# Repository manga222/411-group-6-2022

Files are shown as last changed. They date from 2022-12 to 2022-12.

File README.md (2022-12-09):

# ECE 425 Disco Light Tower

Author: Manuel Garcia, Mercedes Newton, Willenton Bridges, Alice Ma

## Introduction

A light display tower that utilized audio input to create a unique and exciting light show. The tower will change light color and intensity according to the music in order to always create the perfect vibe. This is the perfect product for all ages, specifically anyone who enjoys music and excellent vibes. This is a practical and fun product that we could all see having in our homes.

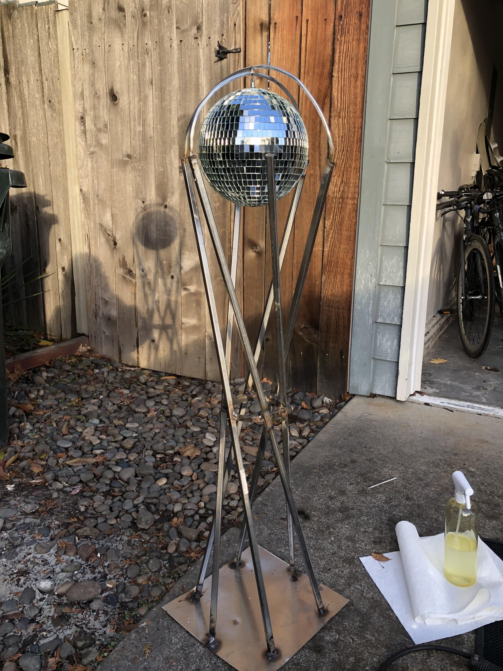
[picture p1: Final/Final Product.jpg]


### Motivation

Searching for a light centerpiece, we identified needs that we had not seen satiated in the current market
Our prototype provides a solution that is…..
* Affordable 
* Portable
* Compatible with any audio
* Unique 
* aesthetically pleasing

## Proposed Design Requirements

* Must change LED color according to surrounding sound and/or music
* Must be aesthetically pleasing
* Must be safe
* Must be user friendly (single power button)
* Must be portable
* Should change LED intensity / frequency according to surrounding sound and/or music
* Should be less than 30lbs
* Should be 2 feet tall
* Should have a metal base
* Should have a disco ball and RGB spotlight
* Should have soft bottom to prevent scratching floor
* May input music internally through microcontroller and use FFT to filter frequency
* May be battery powered
* May have light intensity settings
* May have amplifying speakers

### Physical Design

* Helix shape for optimal height, light, and appearance
* Lights attached on interior of steel bars to prevent harshness
* 6 bars to both allow for a multitude of light strips yet stay lightweight and mobile
* Circuitry placed in base and out of sight
* Disco ball centered and hung at the top of tower

### System Architecture

* ESP-32

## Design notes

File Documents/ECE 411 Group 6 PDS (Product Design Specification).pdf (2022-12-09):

Mercedes Newton
Manuel Garcia
Willenton Bridges
Alice Ma

## ECE 411 Group 6 Product Design Specification (PDS)

Executive Summary/Concept of Operations
Brief project description: A light display tower that utilized audio input to create a unique and exciting light show. The tower will change light color and intensity according to the music in order to always create the perfect vibe. This is the perfect product for all ages, specifically anyone who enjoys music and excellent vibes. This is a practical and fun product that we could all see having in our homes. There is potential for a multitude of different shapes and concepts so this project is full of possibilities.

Photo of Potential appearance:

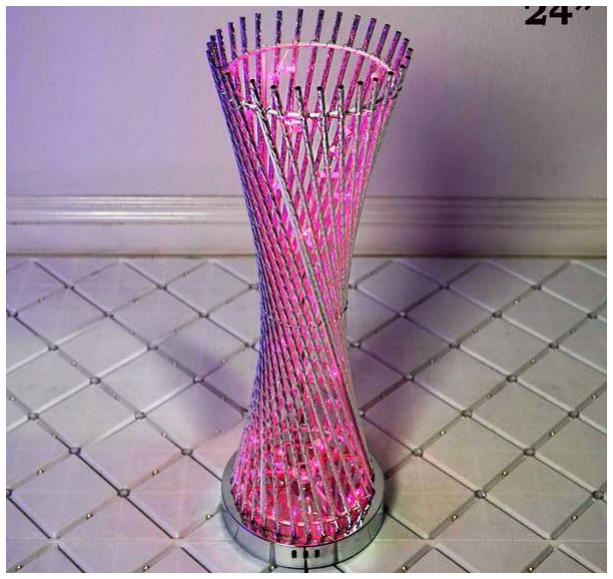
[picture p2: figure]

Brief Market Analysis
The LED light tower is intended to be enjoyed by customers of all ages! Although there are light towers of various shapes and sizes, our product will be slightly different from the competition. Our product will utilize an audio input in order to create a unique and exciting light show. The tower will change both the light color and intensity according to the music. This will always create the perfect vibe regardless of the occasion! We believe our LED light tower will sell for $30, which is slightly higher than the price range compared to the other LED light towers. Our price is slightly higher due to having the feature of the light color and intensity changing based on the pitch of the music.

Requirements

Must change LED color according to surrounding sound and/or music Must be aesthetically pleasing
Must be safe
Must be user friendly (single power button)
Must be portable
Should change LED intensity / frequency according to surrounding sound and/or music
Should be less than 30lbs
Should be 2 feet tall
Should have a metal base
Should have a disco ball and RGB spotlight
Should have soft bottom to prevent scratching floor
May input music internally through microcontroller and use FFT to filter frequency May be battery powered
May have light intensity settings
May have amplifying speakers

System Architecture

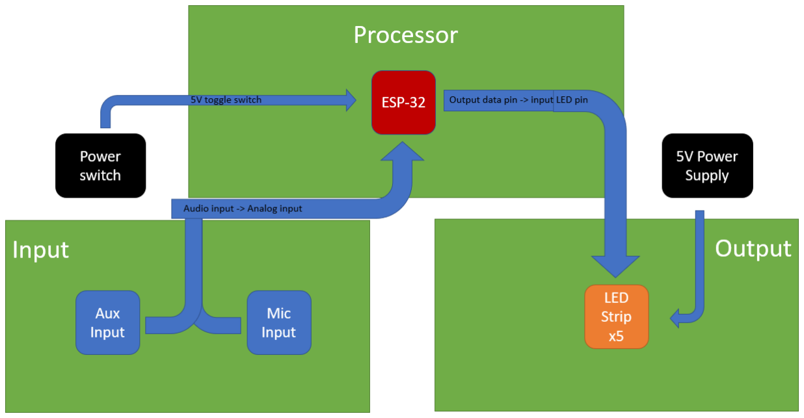
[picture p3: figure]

Design Specification
- Sensor: Microphone, auxiliary input
- Processor: LED controller
- Actuator: LEDs
- Power: 5V power source
- Mechanical design: Helix metal tower with solid base
- Firmware: ESP-32 AT firmware
- Arduino type: ESP-32
- Development environment: Arduino IDE

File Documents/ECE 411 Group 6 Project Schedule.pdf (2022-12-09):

ECE411_gantt | Nov 3, 2022 http://

# Project manager

Project dates | Oct 10, 2022 - Dec 1, 2022
Completion | 70%
Tasks | 25
Resources | 0

Duration | Name | Begin date | End date
8 | Choosing Project | 10/10/22 | 10/19/22
4 | Brainstorm Ideas | 10/10/22 | 10/13/22
2 | Decide on Project | 10/12/22 | 10/13/22
4 | Create Product Design Specifications | 10/14/22 | 10/19/22
11 | Interface Circuitry | 10/19/22 | 11/2/22
8 | Design Preliminary Schematic | 10/19/22 | 10/28/22
9 | Purchase Components | 10/19/22 | 10/31/22
6 | Construct & Test Circuits | 10/26/22 | 11/2/22
2 | Current Driver Circuitry | 10/26/22 | 10/27/22
3 | Level Offset & Gain Circuitry | 10/26/22 | 10/28/22
3 | Integrate Microphone and LED | 10/31/22 | 11/2/22
7 | Microphones and LED | 10/24/22 | 11/1/22
1 | Research A/D Converters | 10/24/22 | 10/24/22
4 | Complete Hardware Design | 10/25/22 | 10/28/22
3 | Purchase LED and Microphone | 10/25/22 | 10/27/22
2 | Construct & Test | 10/31/22 | 11/1/22
12 | System Integtration & Test | 10/26/22 | 11/10/22
4 | Test Breadboard Prototype | 10/31/22 | 11/3/22
7 | Update Schematic and Preliminary Layout | 10/26/22 | 11/3/22
4 | Create a Rough Draft in CAD | 11/3/22 | 11/8/22
3 | Conduct a Design Review | 11/8/22 | 11/10/22
14 | Final Stretch | 11/11/22 | 11/30/22
4 | Update Final Schematic Layout | 11/11/22 | 11/16/22
5 | Send PCD Design to be Printed | 11/17/22 | 11/23/22
6 | Prepare to Demp | 11/23/22 | 11/30/22
ECE411_gantt | Nov 3, 2022
Tasks | 2

# Gantt Chart

3

Duration | Name | Begin date | End date
8.0 day | Choosing Project | 10/10/22 | 10/19/22
4.0 day | Brainstorm Ideas | 10/10/22 | 10/13/22
2.0 day | Decide on Project | 10/12/22 | 10/13/22
4.0 day | Create Product Design... | 10/14/22 | 10/19/22
11.0 day | Interface Circuitry | 10/19/22 | 11/2/22
8.0 day | Design Preliminary Schematic | 10/19/22 | 10/28/22
9.0 day | Purchase Components | 10/19/22 | 10/31/22
6.0 day | Construct & Test Circuits | 10/26/22 | 11/2/22
2.0 day | Current Driver Circuitry | 10/26/22 | 10/27/22
3.0 day | Level Offset & Gain Circuitry | 10/26/22 | 10/28/22
3.0 day | Integrate Microphone and LED | 10/31/22 | 11/2/22
7.0 day | Microphones and LED | 10/24/22 | 11/1/22
1.0 day | Research A/D Converters | 10/24/22 | 10/24/22
4.0 day | Complete Hardware Design | 10/25/22 | 10/28/22
3.0 day | Purchase LED and Microphone | 10/25/22 | 10/27/22
2.0 day | Construct & Test | 10/31/22 | 11/1/22
12.0 day | System Integtration & Test | 10/26/22 | 11/10/22
4.0 day | Test Breadboard Prototype | 10/31/22 | 11/3/22
7.0 day | Update Schematic and ... | 10/26/22 | 11/3/22
4.0 day | Create a Rough Draft in CAD | 11/3/22 | 11/8/22
3.0 day | Conduct a Design Review | 11/8/22 | 11/10/22
14.0 day | Final Stretch | 11/11/22 | 11/30/22
4.0 day | Update Final Schematic Layout | 11/11/22 | 11/16/22
5.0 day | Send PCD Design to be Printed | 11/17/22 | 11/23/22
6.0 day | Prepare to Demp | 11/23/22 | 11/30/22
October 2022 | November 2022 | Dec'2022
10 | 11 | 12 | 13 | 14 | 17 | 18 | 19 | 20 | 21 | 24 | 25 | 26 | 27 | 28 | 31

1

2

3
4

7

8

9 | 10 | 11 | 14 | 15 | 16 | 17 | 18 | 21 | 22 | 23 | 24 | 25 | 28 | 29 | 30

1

# Resources Chart

4

Name | Default role
October 2022 | November 2022 | Dec'2022
10 | 11 | 12 | 13 | 14 | 17 | 18 | 19 | 20 | 21 | 24 | 25 | 26 | 27 | 28 | 31

1

2

3
4

7

8

9 | 10 | 11 | 14 | 15 | 16 | 17 | 18 | 21 | 22 | 23 | 24 | 25 | 28 | 29 | 30

1

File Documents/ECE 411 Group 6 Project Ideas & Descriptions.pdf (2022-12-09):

Mercedes Newton
Manuel Garcia
Willenton Bridges
Alice Ma

## ECE 411 Group 6 Project Ideas & Descriptions

LED Light Tower

Brief project description: A light display tower that utilized audio input to create a unique and exciting light show. The tower will change light color and intensity according to the music in order to always create the perfect vibe.

Photo:

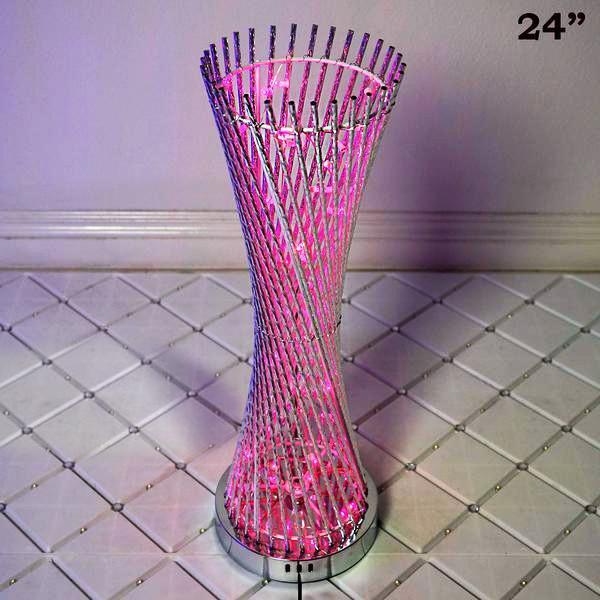
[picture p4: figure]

Sensors: Mic / Aux input

Controllers: ESP-32, LED controller

Actuators: LED’s

We like this project because: This is a practical and fun product that we could all see having in our homes. We liked the customizability and the fact that we could produce several different shapes and designs. This seems like the perfect balance of ambitious and feasible and therefore we will be pursuing this project.

Willenton Bridges
Alice Ma

Bath Time Water Temperature Sensor

Brief project description: A light up bath toy that indicates the temperature of the water with leds. Similar concept to the photo below, but with more utility as it will react to its environment and let the user know temperature.

Photo:

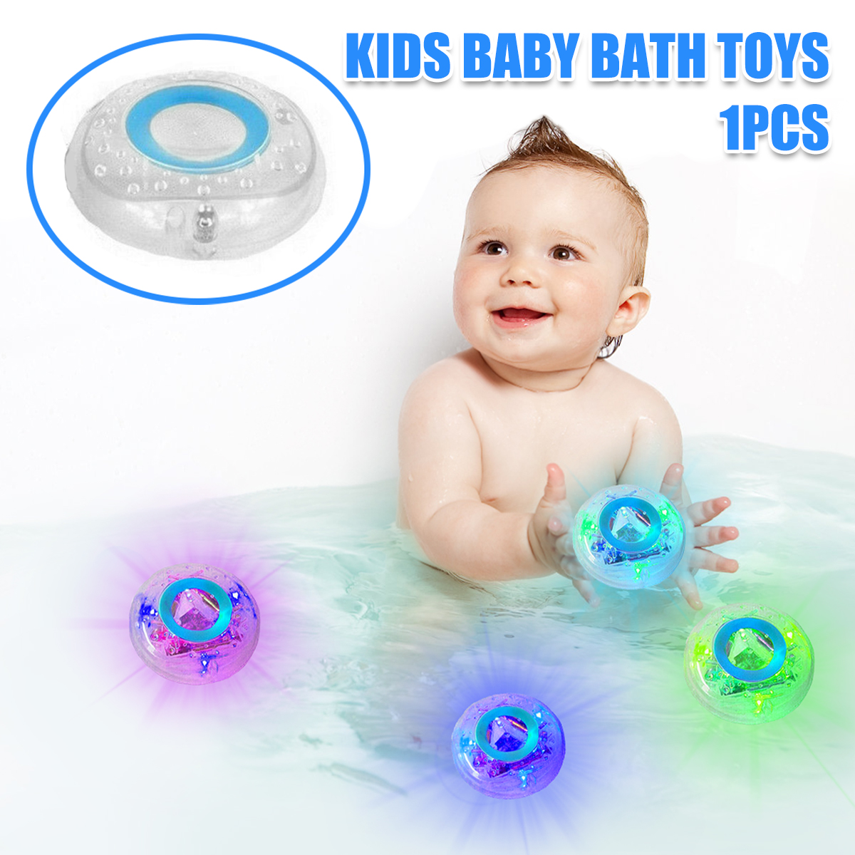
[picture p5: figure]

Sensors: Temperature sensor

Controllers: ESP-32

Actuators: RGB leds

We like this project because: This project is a fun and exciting way to incorporate light and temperature to create a helpful product. This toy could be used to help parents indicate the temperature of the water for small children, or to help let bath enthusiasts know when it is time to grab a glass of wine and settle in.

Smart Aeroponics Setup

Brief project description: This product is a self watering plant tower. The plants will be placed at different heights along the tower and the desired amount of water will be

Willenton Bridges
Alice Ma
dispersed from the main tank as depicted below.

Photo:

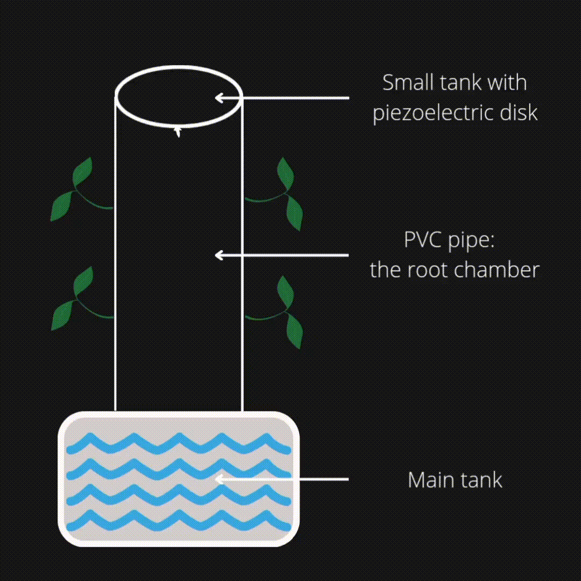
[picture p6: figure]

Sensors: PH sensor, Moisture sensor, Light sensor

Controllers: ESP-32

Actuators: Water pump, Full spectrum LED bulbs, nutrient pump

We like this project because: This is an exciting project that combines the passion of growing plants that each of our group members have, with an integrated electronics project. This would also be a fun project to use after this class is over, and would be something that we would like to keep around.

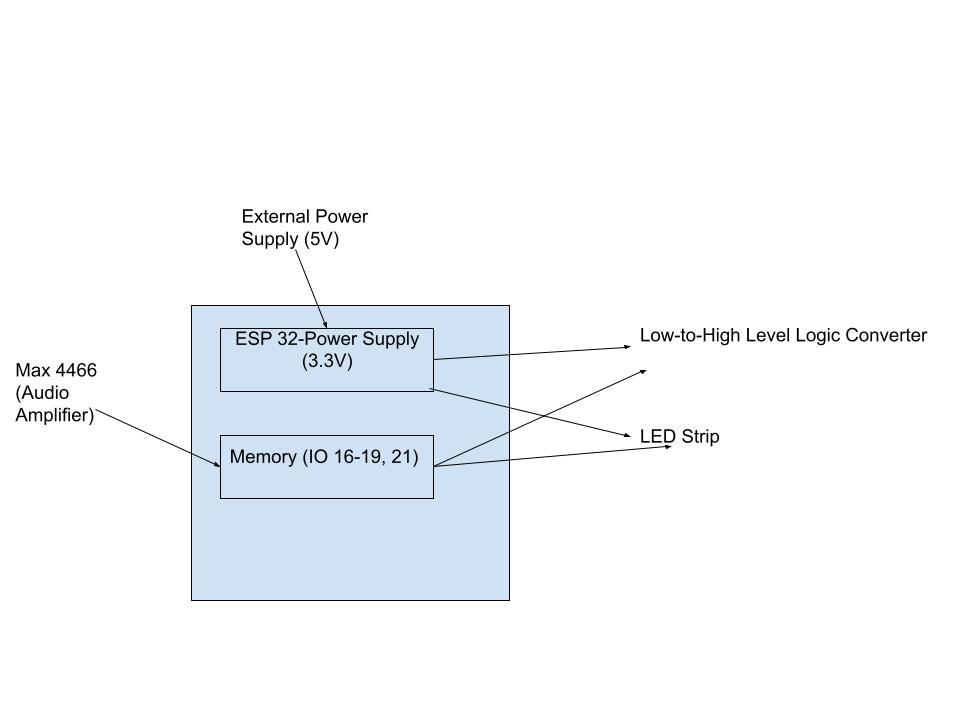
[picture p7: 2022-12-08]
Functional Decomposition/Level 1 ESP-32.jpg

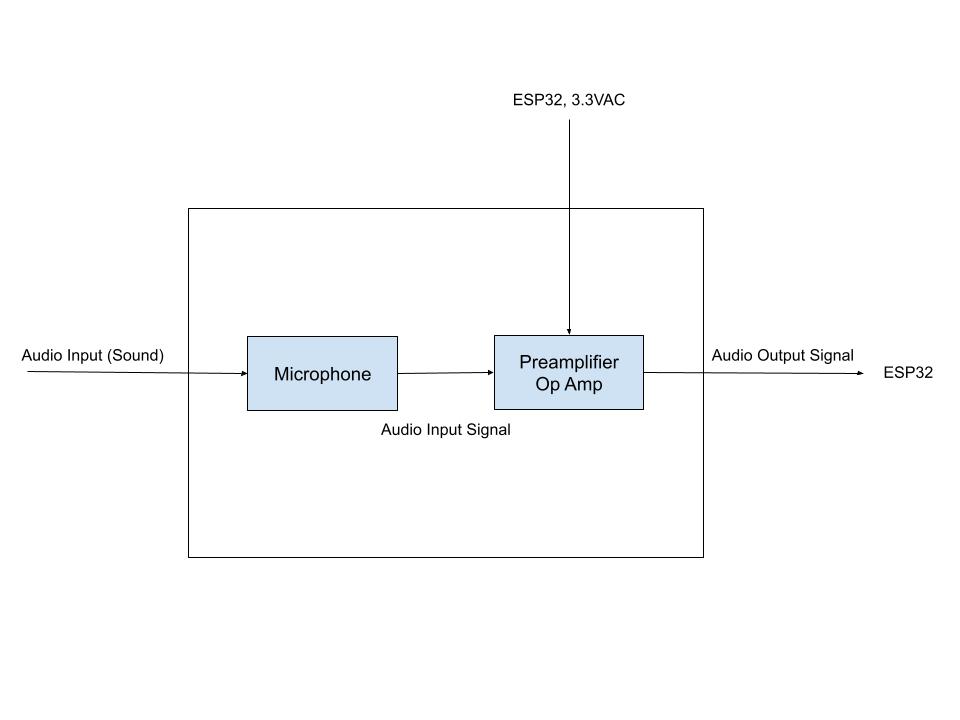
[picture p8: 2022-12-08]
Functional Decomposition/Level 1 Audio Amp.jpg

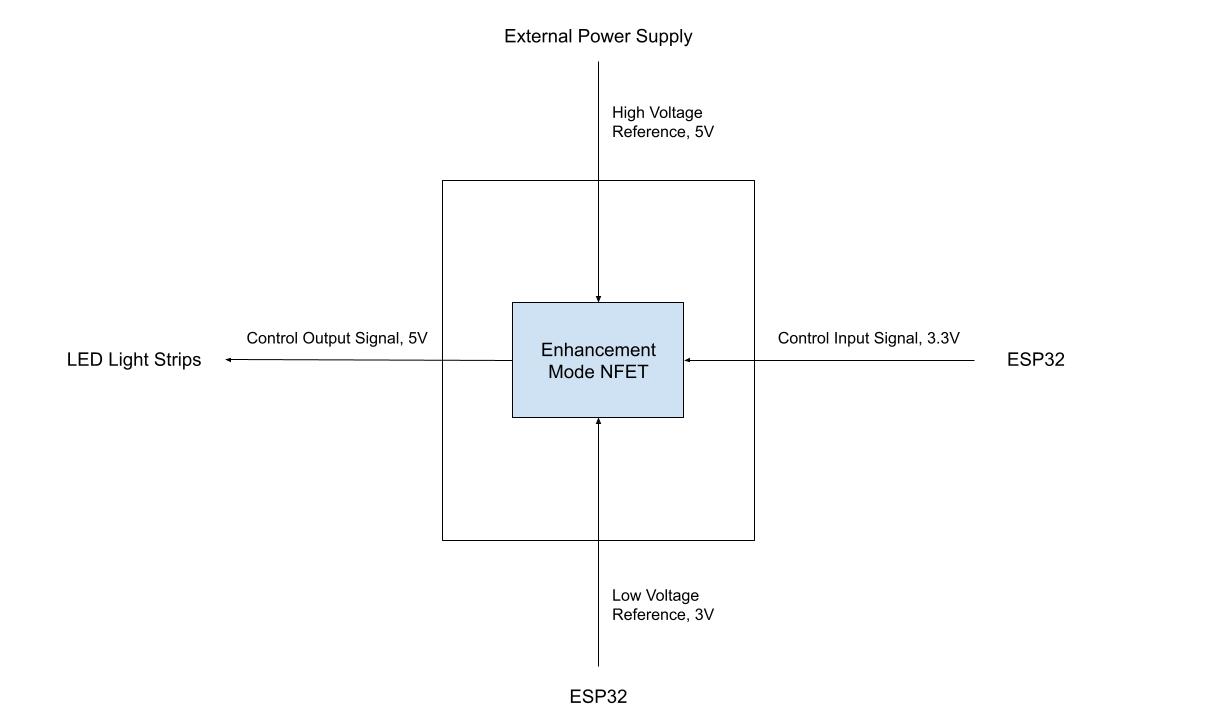
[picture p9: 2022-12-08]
Functional Decomposition/Level 1 Low to High Level Logic Converter.jpg

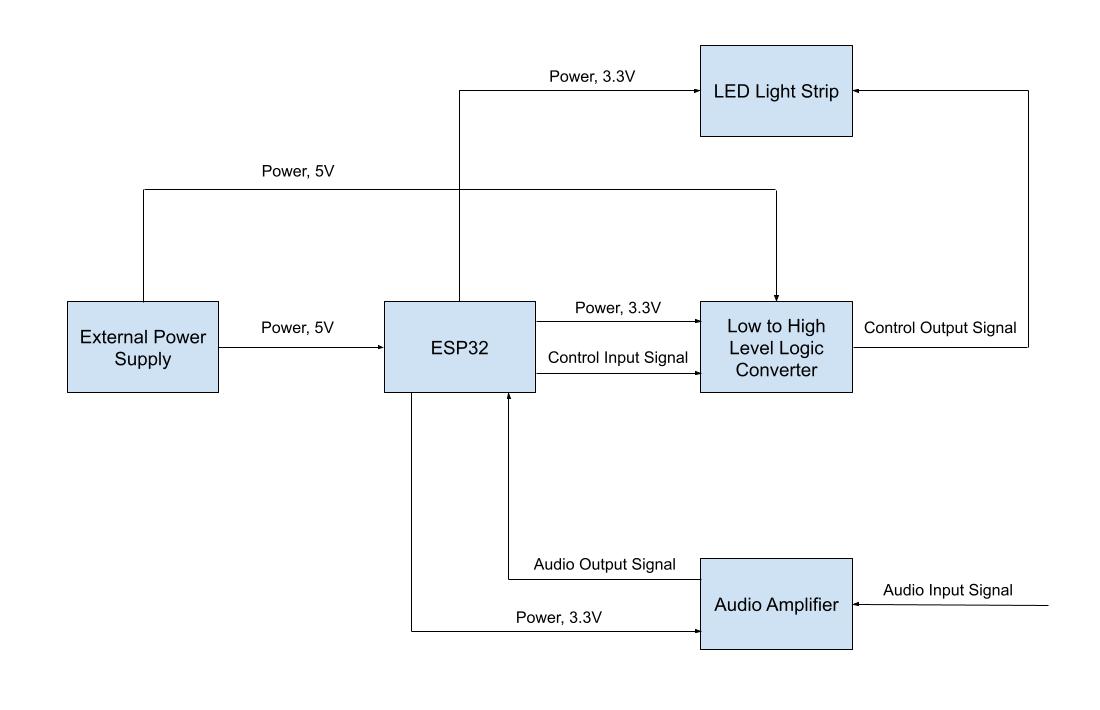
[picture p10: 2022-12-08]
Functional Decomposition/Level 0 Functional Decomposition.jpg

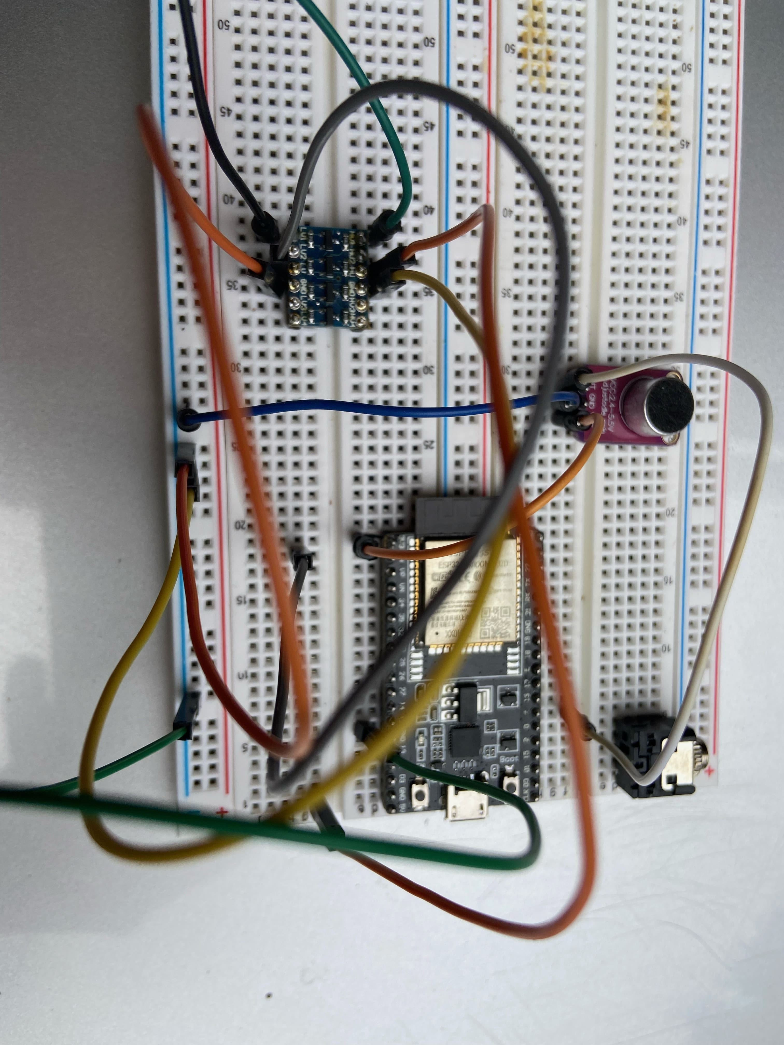
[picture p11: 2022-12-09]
Prototype/Breadboard Prototype.jpeg

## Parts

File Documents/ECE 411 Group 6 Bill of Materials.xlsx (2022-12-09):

Bill Of Materials for: Team 6, Light Tower
Last modified: 11/10/2022
PCB version: 4
BOM revision: 2 |  | P/NP | = Place/Not Place (components marked NP are not stuffed on the board)
ID | Qty | Ref Des | Value | Package | ICs | Description
1 | 3 | C1, C3, C21 | 22 uF/10V (20%) | 603 | Capacitor | Ceramic Capacitor
2 | 4 | C9, C14, C19, C22 | 0.1 uF/50V (10%) | 402 | Capacitor | Ceramic Capacitor
3 | 1 | C20 | 4.7 uF/6.3V (10%) | 402 | Capacitor | Ceramic Capacitor
4 | 1 | D1 | RED LED | 603 | Diode | light-emitting diode: Red
5 | 1 | D2 | ESP-WROOM-32 | ESP32_MODULE | Module | ESP32-WROOM-32 (32 Mbit)
6 | 1 | D3 | BAT760-7 | SOD323 | Diode | Schottky Diode,Vrrm=30V, Vr=21V, I=1A, IFSM=5.5A
7 | 3 | D4, D5, D6 | LESD5D5.0CT1G | SOD-523 | Diode | ESD, TVS Diode, 5V
8 | 1 | J1 | Micro USB Type B Female 5 Pin DIP/插件 | USB_5P | Connector | Micro USB
9 | 2 | Q1, Q2 | S8050 | SOT-23-3 | Transistor | Transistor
10 | 2 | R2, R24 | 2K (5%) | 402 | Resistor | Chip Resistors
11 | 3 | R11, R21, R22 | 10K (5%) | 402 | Resistor | Chip Resistors
12 | 2 | R17, R18 | 0R (5%) | 402 | Resistor | Chip Resistors
13 | 1 | R25 | 22.1K (5%) | 402 | Resistor | Chip Resistors
14 | 1 | R26 | 47.5K (5%) | 402 | Resistor | Chip Resistors
15 | 2 | SW1, SW2 | SW push button | Tact Switch | Tact Switch | (reset button, 2-pin, 3x4x2, SMT)
16 | 2 | J2, J3 | CON19X1_2P54 | CON19_2P54 | Connector | Male PCB Single Row Straight Header Connector, 2.54 mm Pitch, 19 Pins
17 | 1 | U1 | CP2102N-A01-GQFN28 | CP2102_QFN_28P | Interface ICs | USB-to-UART,USB2.0 full speed, data rate up to 3M baud
18 | 1 | U2 | AMS1117-3.3 | SOT-223 | Power ICs | LDO, 5V 转 3.3V 固定输出, 1A, SOT-223 (LDO, 5V/3.3V, 1A, SOT-223)
NEED TO SORT
Item | Qty | Reference(s) | Value | LibPart
1 | 3 | C1, C2, C8 | 22uF | Device:C
2 | 1 | C3 | 4.7uF | Device:C
3 | 6 | C4, C5, C6, C7, C9, C10 | 0.1uF | Device:C
4 | 1 | C11 | 10uF | Device:C
5 | 1 | C12 | 0.01uF | Device:C
6 | 1 | C13 | 100pF | Device:C
7 | 1 | D1 | RED LED | Device:LED
8 | 3 | D2, D4, D5 | D_TVS | Device:D_TVS
9 | 1 | D3 | D_Zener | Device:D_Zener
10 | 5 | D6, D7, D8, D9, D10 | WS2812 | LED:WS2812
11 | 2 | FB1, FB2 | FerriteBead | Device:FerriteBead
12 | 1 | J1 | USB_B_Micro | Connector:USB_B_Micro
13 | 1 | J2 | Conn_01x04_Male | Connector:Conn_01x04_Male
14 | 3 | J3, J4, J5 | Conn_01x08_Male | Connector:Conn_01x08_Male
15 | 1 | J6 | Conn_01x03_Male | Connector:Conn_01x03_Male
16 | 1 | MK1 | Microphone_Condenser | Device:Microphone_Condenser
17 | 2 | Q1, Q2 | QNPN | pspice:QNPN
18 | 5 | Q3, Q4, Q5, Q6, Q7 | BSS138 | Transistor_FET:BSS138
19 | 1 | R1 | 2K | Device:R
20 | 1 | R2 | 22.1k | Device:R
21 | 1 | R3 | 47.5k | Device:R
22 | 1 | R4 | 2k | Device:R
23 | 4 | R5, R7, R9, R10 | 10k | Device:R
24 | 2 | R6, R8 | 0 | Device:R
25 | 2 | R11, R12 | 1K | Device:R
26 | 1 | R13 | 22K | Device:R
27 | 2 | R14, R15 | 1M | Device:R
28 | 1 | R16 | 100K | Device:R
29 | 10 | R17, R18, R19, R20, R21, R22, R23, R24, R25, R26 | 10K | Device:R
30 | 1 | RV1 | 100K_Potentiometer | Device:R_Potentiometer
31 | 2 | SW1, SW2 | SW_MEC_5G | Switch:SW_MEC_5G
32 | 1 | U1 | AMS1117-3.3 | Regulator_Linear:AMS1117-3.3
33 | 1 | U2 | CP2102N-Axx-xQFN28 | Interface_USB:CP2102N-Axx-xQFN28
34 | 1 | U3 | ESP32-WROOM-32 | RF_Module:ESP32-WROOM-32
35 | 1 | U4 | MAX4466 | Custom_Parts:MAX4466
VERSION INFO
Rev | Date | Notes

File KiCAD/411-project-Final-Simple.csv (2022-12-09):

Source: | C:\Users\manue\Documents\KiCad\411-project-Final-Simple\411-project-Final-Simple.kicad_sch
Date: | 11/13/2022 10:49:24 PM
Tool: | Eeschema (6.0.8)
Generator: | C:\Program Files\KiCad\6.0\bin\scripting\plugins/bom_csv_grouped_by_value.py
Component Count: | 50
Individual Components:
Item | Qty | Reference(s) | Value | LibPart | Footprint | Datasheet | MANUFACTURER | PARTREV
 |  | C1 | 0.1uF | Device:C |  | ~
 |  | C2 | 10uF | Device:C |  | ~
 |  | C3 | 0.01uF | Device:C |  | ~
 |  | C4 | 100pF | Device:C |  | ~
 |  | D1 | WS2812 | LED:WS2812 | LED_SMD:LED_WS2812_PLCC6_5.0x5.0mm_P1.6mm | https://cdn-shop.adafruit.com/datasheets/WS2812.pdf
 |  | D2 | WS2812 | LED:WS2812 | LED_SMD:LED_WS2812_PLCC6_5.0x5.0mm_P1.6mm | https://cdn-shop.adafruit.com/datasheets/WS2812.pdf
 |  | D3 | WS2812 | LED:WS2812 | LED_SMD:LED_WS2812_PLCC6_5.0x5.0mm_P1.6mm | https://cdn-shop.adafruit.com/datasheets/WS2812.pdf
 |  | D4 | WS2812 | LED:WS2812 | LED_SMD:LED_WS2812_PLCC6_5.0x5.0mm_P1.6mm | https://cdn-shop.adafruit.com/datasheets/WS2812.pdf
 |  | D5 | WS2812 | LED:WS2812 | LED_SMD:LED_WS2812_PLCC6_5.0x5.0mm_P1.6mm | https://cdn-shop.adafruit.com/datasheets/WS2812.pdf
 |  | D6 | WS2812 | LED:WS2812 | LED_SMD:LED_WS2812_PLCC6_5.0x5.0mm_P1.6mm | https://cdn-shop.adafruit.com/datasheets/WS2812.pdf
 |  | D7 | WS2812 | LED:WS2812 | LED_SMD:LED_WS2812_PLCC6_5.0x5.0mm_P1.6mm | https://cdn-shop.adafruit.com/datasheets/WS2812.pdf
 |  | FB1 | FerriteBead | Device:FerriteBead |  | ~
 |  | FB2 | FerriteBead | Device:FerriteBead |  | ~
 |  | J1 | Conn_01x03_Male | Connector:Conn_01x03_Male |  | ~
 |  | J2 | Conn_01x02_Female | Connector:Conn_01x02_Female |  | ~
 |  | J3 | Conn_01x19_Female | Connector:Conn_01x19_Female |  | ~
 |  | J4 | Conn_01x19_Female | Connector:Conn_01x19_Female |  | ~
 |  | J5 | Conn_01x07_Female | Connector:Conn_01x07_Female |  | ~
 |  | MK1 | Microphone_Condenser | Device:Microphone_Condenser |  | ~
 |  | Q1 | BSS138 | Transistor_FET:BSS138 | Package_TO_SOT_SMD:SOT-23 | https://www.onsemi.com/pub/Collateral/BSS138-D.PDF
 |  | Q2 | BSS138 | Transistor_FET:BSS138 | Package_TO_SOT_SMD:SOT-23 | https://www.onsemi.com/pub/Collateral/BSS138-D.PDF
 |  | Q3 | BSS138 | Transistor_FET:BSS138 | Package_TO_SOT_SMD:SOT-23 | https://www.onsemi.com/pub/Collateral/BSS138-D.PDF
 |  | Q4 | BSS138 | Transistor_FET:BSS138 | Package_TO_SOT_SMD:SOT-23 | https://www.onsemi.com/pub/Collateral/BSS138-D.PDF
 |  | Q5 | BSS138 | Transistor_FET:BSS138 | Package_TO_SOT_SMD:SOT-23 | https://www.onsemi.com/pub/Collateral/BSS138-D.PDF
 |  | Q6 | BSS138 | Transistor_FET:BSS138 | Package_TO_SOT_SMD:SOT-23 | https://www.onsemi.com/pub/Collateral/BSS138-D.PDF
 |  | Q7 | BSS138 | Transistor_FET:BSS138 | Package_TO_SOT_SMD:SOT-23 | https://www.onsemi.com/pub/Collateral/BSS138-D.PDF
 |  | R1 | 1K | Device:R |  | ~
 |  | R2 | 1K | Device:R |  | ~
 |  | R3 | 22K | Device:R |  | ~
 |  | R4 | 1M | Device:R |  | ~
 |  | R5 | 1M | Device:R |  | ~
 |  | R6 | 100K | Device:R |  | ~
 |  | R7 | 10K | Device:R |  | ~
 |  | R8 | 10K | Device:R |  | ~
 |  | R9 | 10K | Device:R |  | ~
 |  | R10 | 10K | Device:R |  | ~
 |  | R11 | 10K | Device:R |  | ~
 |  | R12 | 10K | Device:R |  | ~
 |  | R13 | 10K | Device:R |  | ~
 |  | R14 | 10K | Device:R |  | ~
 |  | R15 | 10K | Device:R |  | ~
 |  | R16 | 10K | Device:R |  | ~
 |  | R17 | 10K | Device:R |  | ~
 |  | R18 | 10K | Device:R |  | ~
 |  | R19 | 10K | Device:R |  | ~
 |  | R20 | 10K | Device:R |  | ~
 |  | RV1 | 100K_Potentiometer | Device:R_Potentiometer |  | ~
 |  | RV2 | 10k_Potentiometer | Device:R_Potentiometer |  | ~
 |  | U1 | MAX4466 | Custom_Parts:MAX4466
 |  | U2 | ESP32-DEVKITC-32D | ESP32-DEVKITC-32D:ESP32-DEVKITC-32D | MODULE_ESP32-DEVKITC-32D |  | Espressif Systems | 4
Collated Components:
Item | Qty | Reference(s) | Value | LibPart | Footprint | Datasheet | MANUFACTURER | PARTREV
1 | 1 | C1 | 0.1uF | Device:C |  | ~
2 | 1 | C2 | 10uF | Device:C |  | ~
3 | 1 | C3 | 0.01uF | Device:C |  | ~
4 | 1 | C4 | 100pF | Device:C |  | ~
5 | 7 | D1, D2, D3, D4, D5, D6, D7 | WS2812 | LED:WS2812 | LED_SMD:LED_WS2812_PLCC6_5.0x5.0mm_P1.6mm | https://cdn-shop.adafruit.com/datasheets/WS2812.pdf
6 | 2 | FB1, FB2 | FerriteBead | Device:FerriteBead |  | ~
7 | 1 | J1 | Conn_01x03_Male | Connector:Conn_01x03_Male |  | ~
8 | 1 | J2 | Conn_01x02_Female | Connector:Conn_01x02_Female |  | ~
9 | 2 | J3, J4 | Conn_01x19_Female | Connector:Conn_01x19_Female |  | ~
10 | 1 | J5 | Conn_01x07_Female | Connector:Conn_01x07_Female |  | ~
11 | 1 | MK1 | Microphone_Condenser | Device:Microphone_Condenser |  | ~
12 | 7 | Q1, Q2, Q3, Q4, Q5, Q6, Q7 | BSS138 | Transistor_FET:BSS138 | Package_TO_SOT_SMD:SOT-23 | https://www.onsemi.com/pub/Collateral/BSS138-D.PDF
13 | 2 | R1, R2 | 1K | Device:R |  | ~
14 | 1 | R3 | 22K | Device:R |  | ~
15 | 2 | R4, R5 | 1M | Device:R |  | ~
16 | 1 | R6 | 100K | Device:R |  | ~
17 | 14 | R7, R8, R9, R10, R11, R12, R13, R14, R15, R16, R17, R18, R19, R20 | 10K | Device:R |  | ~
18 | 1 | RV1 | 100K_Potentiometer | Device:R_Potentiometer |  | ~
19 | 1 | RV2 | 10k_Potentiometer | Device:R_Potentiometer |  | ~
20 | 1 | U1 | MAX4466 | Custom_Parts:MAX4466
21 | 1 | U2 | ESP32-DEVKITC-32D | ESP32-DEVKITC-32D:ESP32-DEVKITC-32D | MODULE_ESP32-DEVKITC-32D |  | Espressif Systems | 4

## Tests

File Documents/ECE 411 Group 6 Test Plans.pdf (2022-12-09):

Test Author: Mercedes Newton
Test Case Name | Disco Tower Test 1: Volume compatatability test | Test ID # | Disco-01
Description | Simulate variety of volumes and check volume threshhold | Type: | White Box

Tester Information:

| Name of Tester: | Mercedes Newton | Date | tbd
| HW/SW Version: | Version 1.0 | Time: | tbd
| Setup: | place JBL speaker within 2 feet of tower. Increment volume in correlation with potentiometer and record what
Step | Action | Expected result | PASS | FAIL | N/A | Comments
1 | 2 volume bars (min) | FAIL
2 | 4 volume bars | FAIL
3 | 6 volume bars | PASS
4 | 8 volume bars | PASS
5 | 10 volume bars | PASS
6 | 12 volume bars | PASS
7 | 14 volume bars | PASS
8 | 16 volume bars (max) | PASS
| Overall Test Result

Test Author: Mercedes Newton
Test Case Name | Disco Tower Test 2: Music genre compatatability test | Test ID # | Disco-02
Description | Play different songs and generes to see which genre creates most compelling light show. | Type: | White Box

Tester Information:

| Name of Tester: | Mercedes Newton | Date | tbd
| HW/SW Version: | Version 1.0 | Time: | tbd
| Setup: | Place speaker within 2 feet of tower. Play each song to completion and review light show generated. If light show is visually appealing, and creates varried tower reaction mark as pass.
Step | Action | Expected result | PASS | FAIL | N/A | Comments
1 | Upbeat instrumental jazz (Lester Young) | PASS
2 | calming jazz | FAIL
3 | German techno Funk (Boris Brejcha) PASS

4 | rap (MF DOOM) | PASS
5 | 80s pop (Michael Jackson) | PASS
6 | pop (Doja cat, Harry Styles) | PASS
7 | classical | FAIL
8 | Abba | PASS

9
| Overall Test Result

Test Author: Mercedes Newton
Test Case Name | Disco Tower Test 3: exterior noise | Test ID # | Disco-03
Description | Simulate talking and party noise to test for ability to descriminate | Type: | White Box

Tester Information:

| Name of Tester: | Mercedes Newton | Date | tbd
| HW/SW Version: | Version 1.0 | Time: | tbd
| Setup: | Place tower in center of space next to speaker set with constant music at medium volume (8 bars). simulate noise by talking/creating different noises in the same room within 3-8ft proximatey.
Step | Action | Expected result | PASS | FAIL | N/A | Comments
1 | quiet talking | PASS
2 | medium talking | PASS
3 | loud talking | FAIL
4 | yelling | FAIL
5 | door closing/slamming | PASS
6 | stopping/loud steps | PASS
7 | clapping/snapping | FAIL
8 | phone ringtone | FAIL
| Overall Test Result

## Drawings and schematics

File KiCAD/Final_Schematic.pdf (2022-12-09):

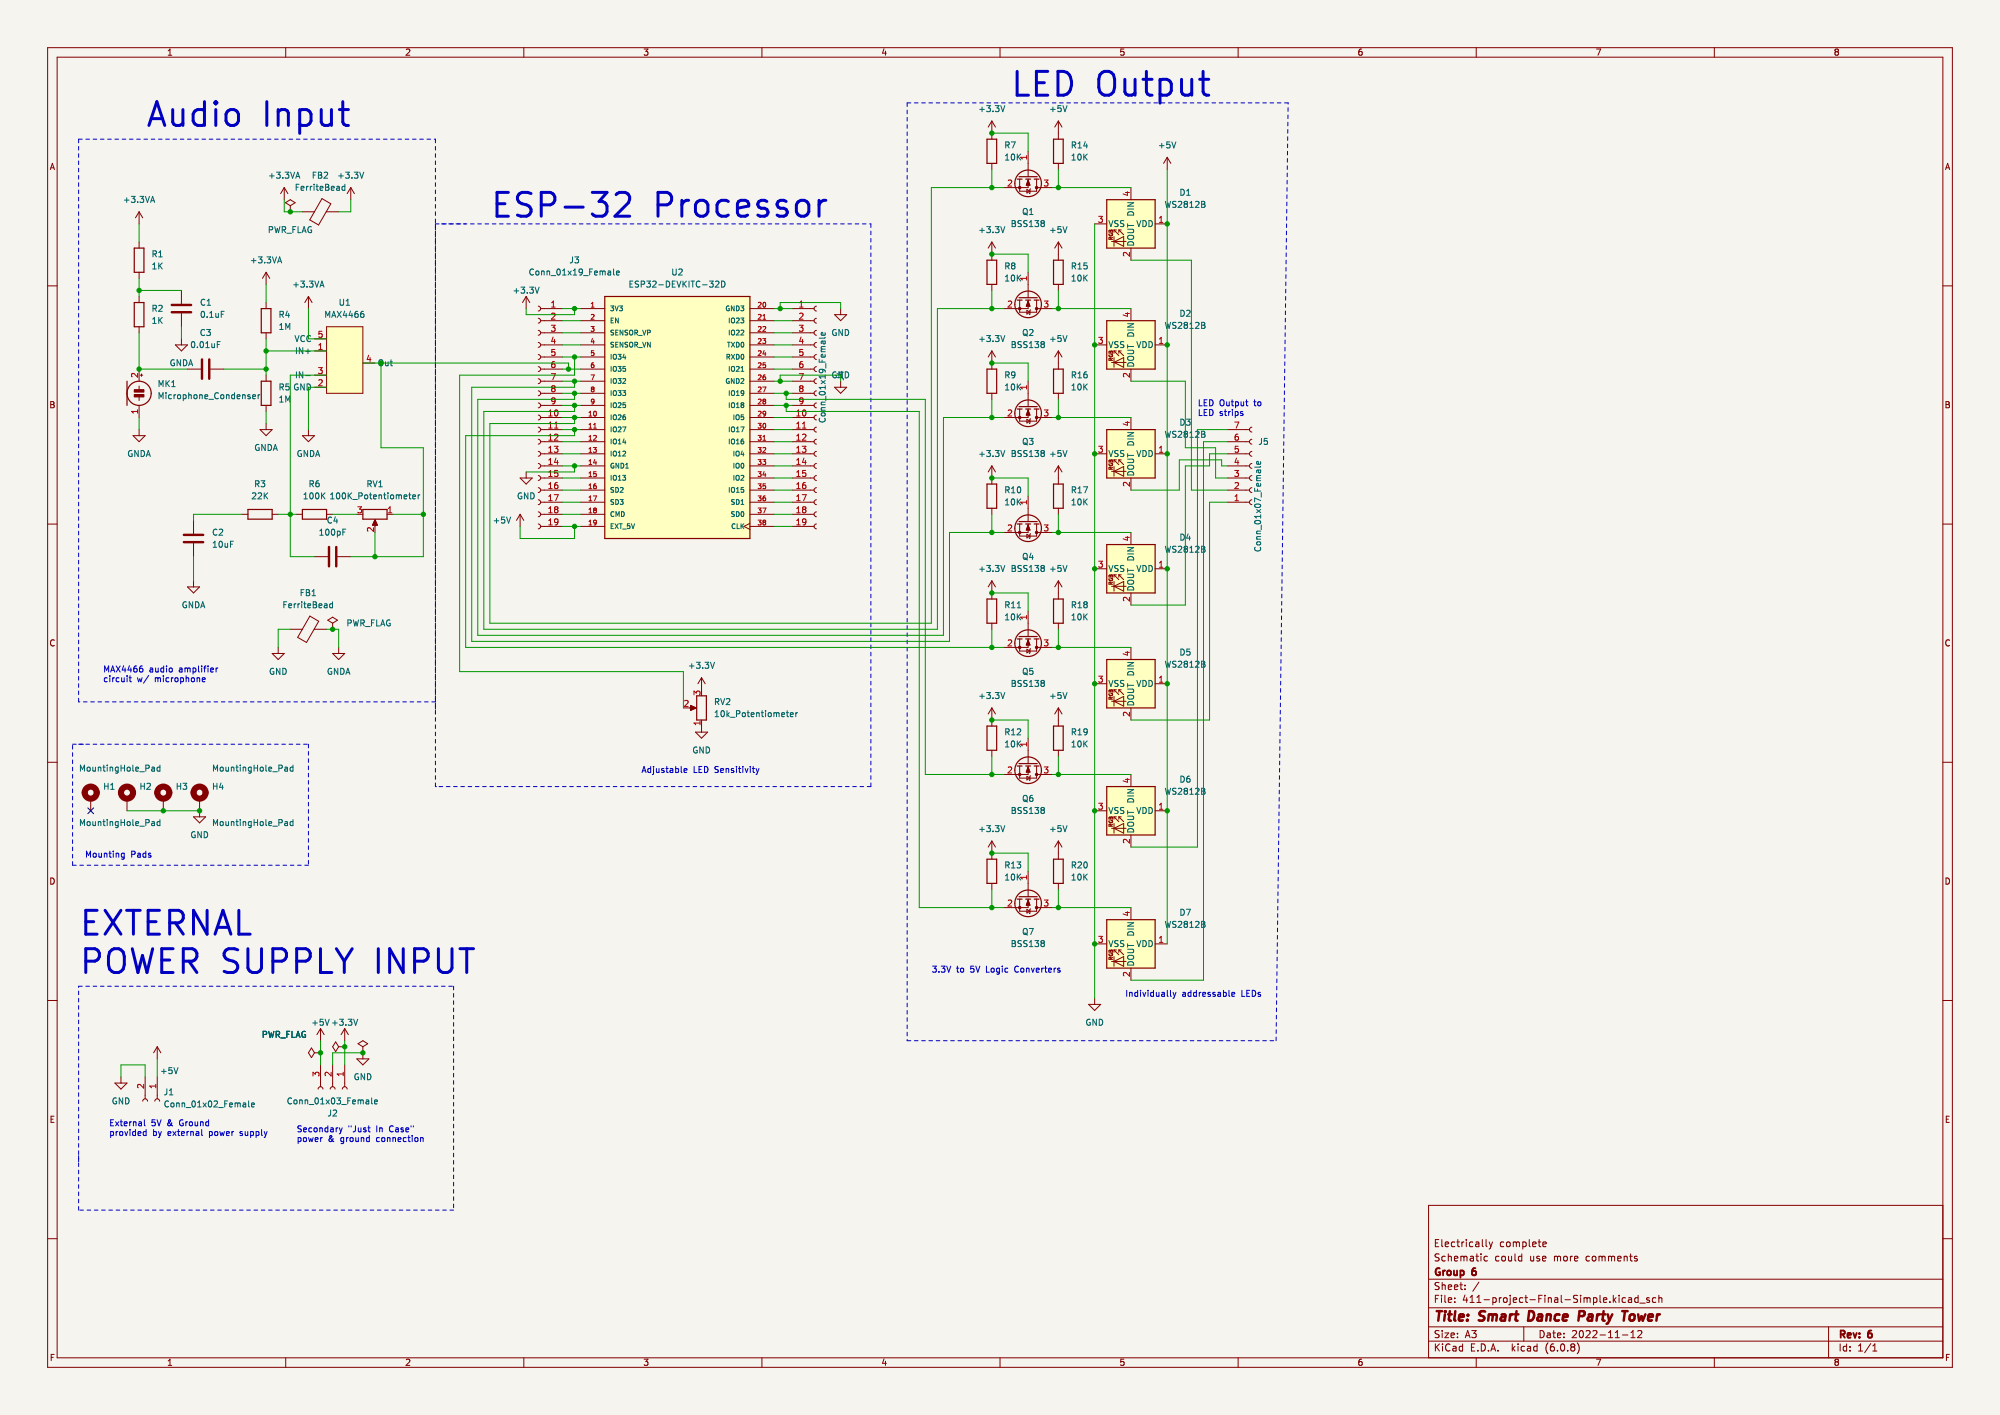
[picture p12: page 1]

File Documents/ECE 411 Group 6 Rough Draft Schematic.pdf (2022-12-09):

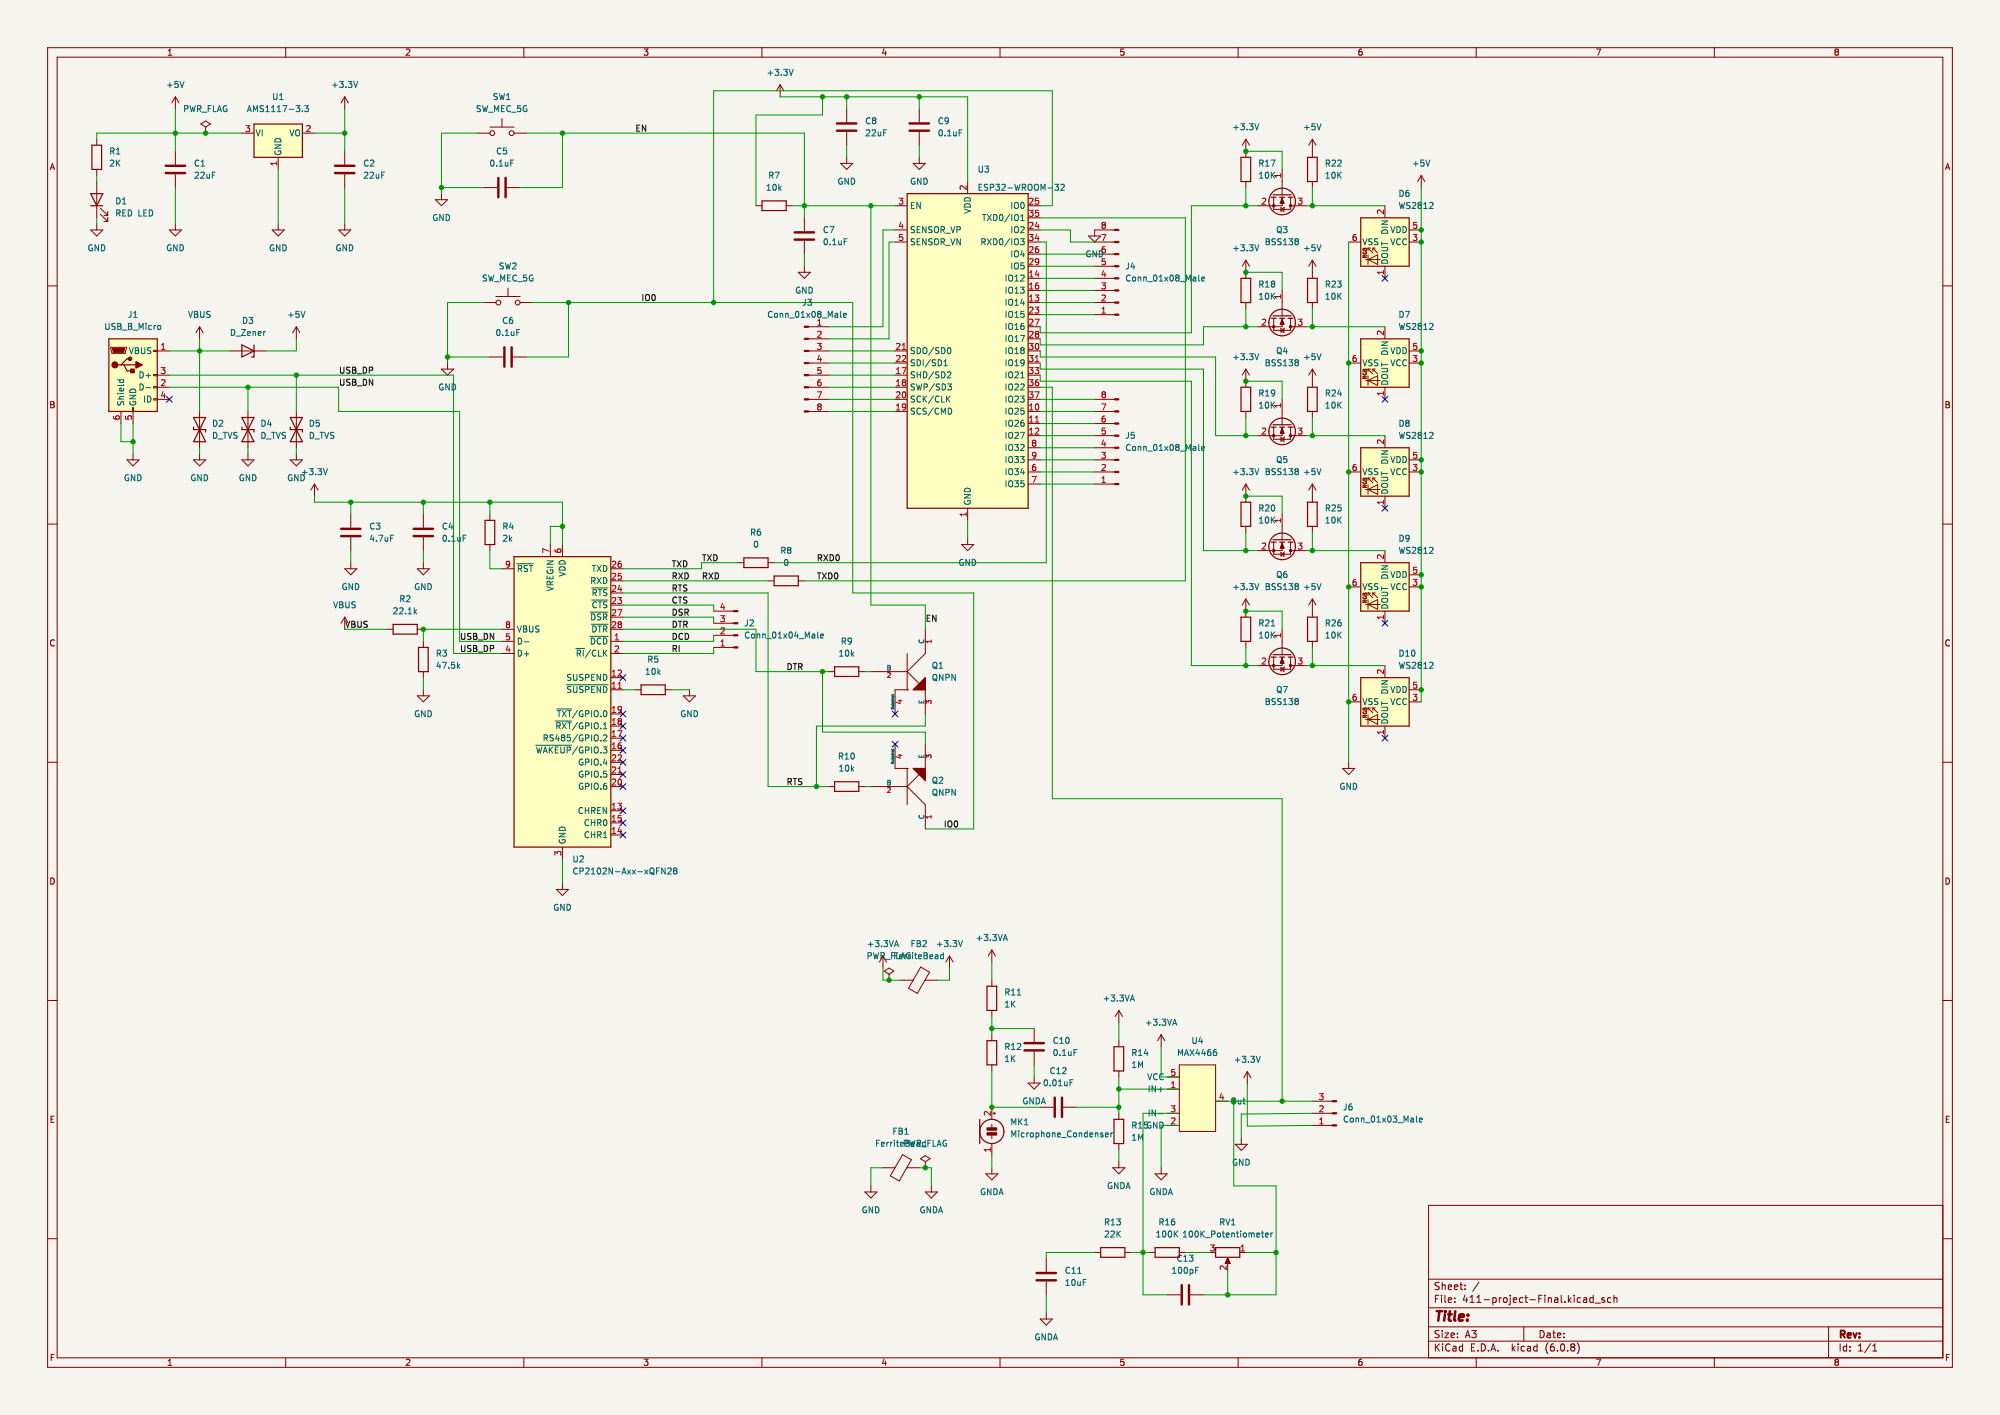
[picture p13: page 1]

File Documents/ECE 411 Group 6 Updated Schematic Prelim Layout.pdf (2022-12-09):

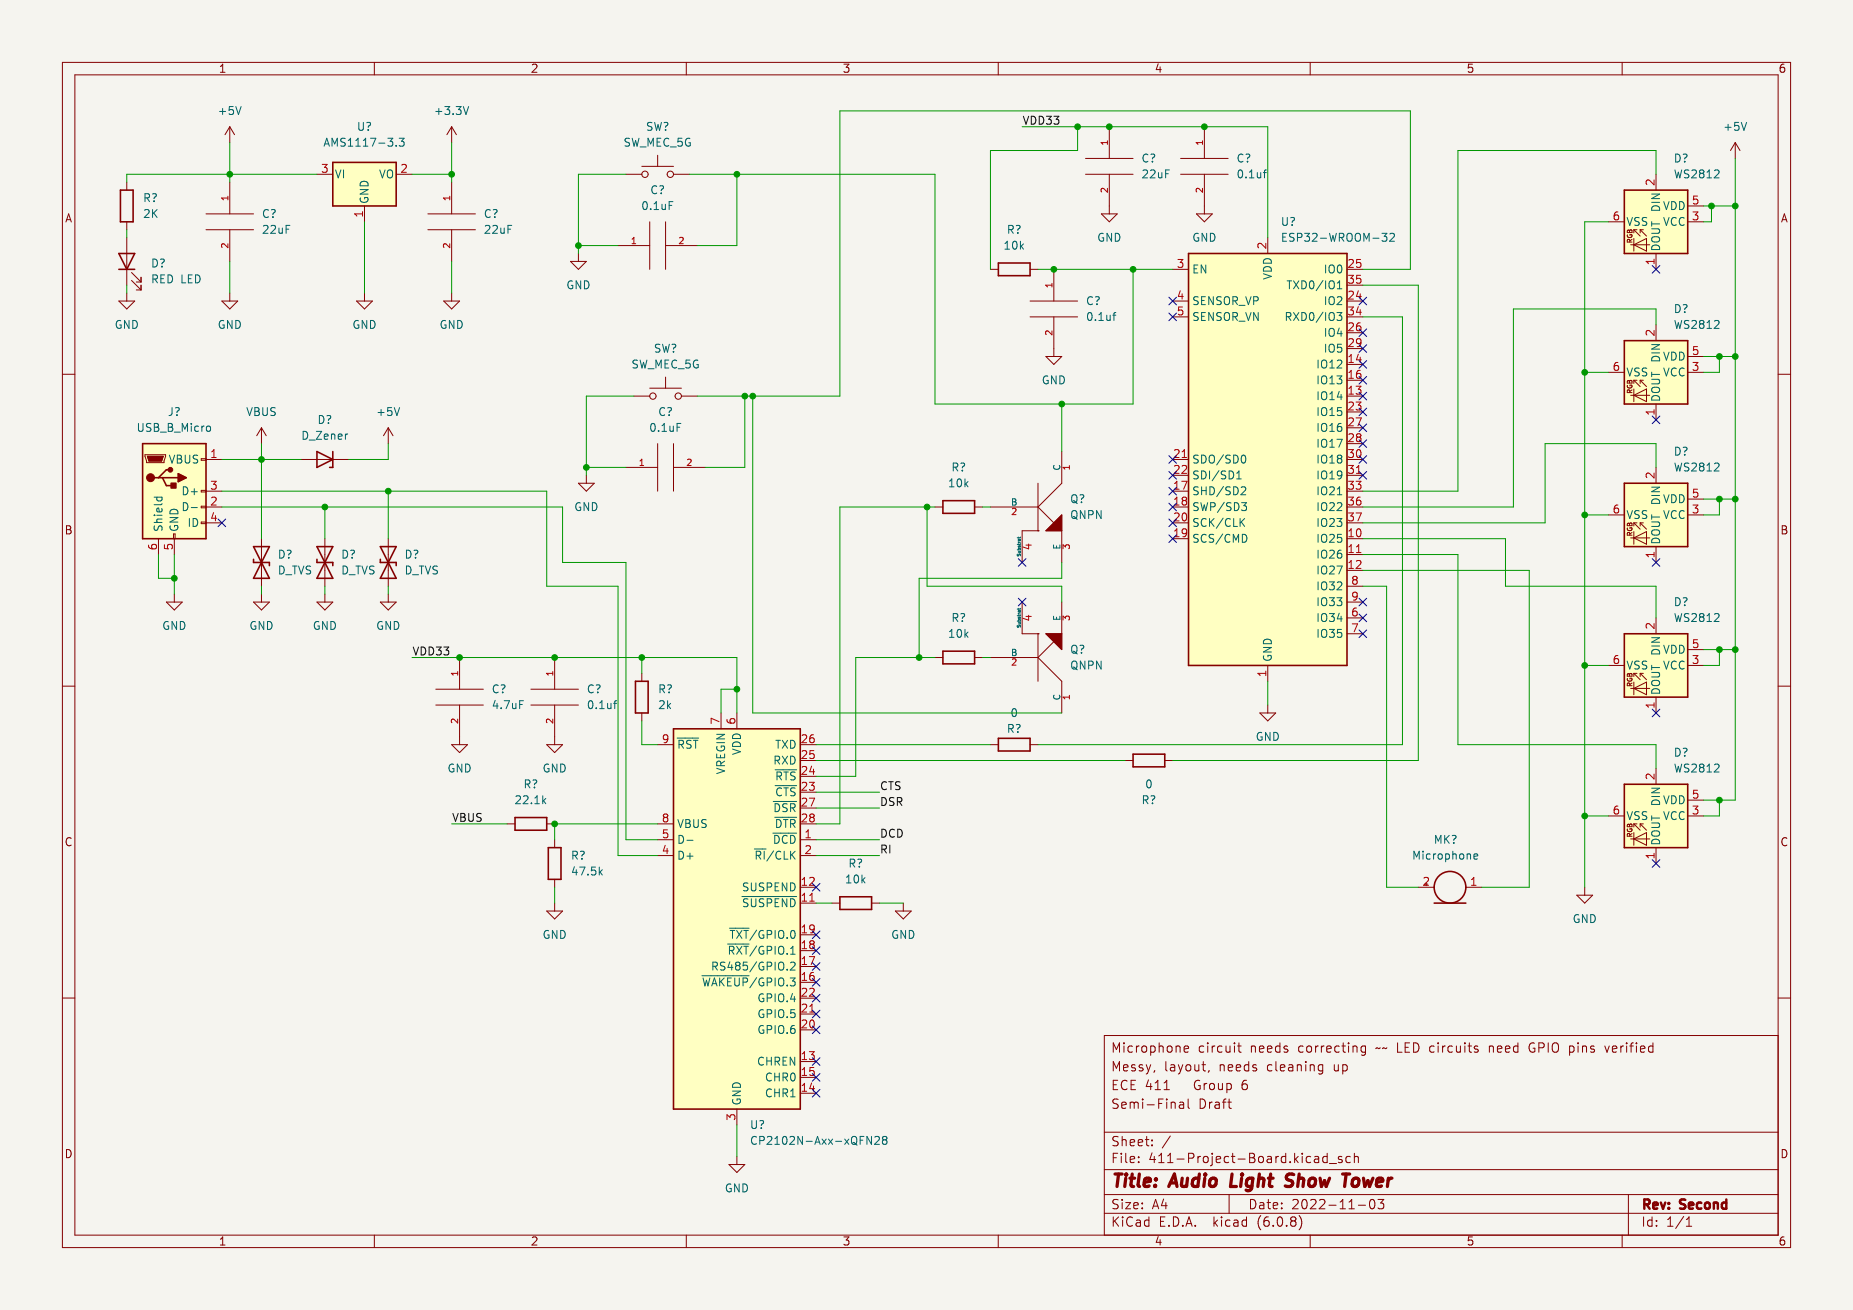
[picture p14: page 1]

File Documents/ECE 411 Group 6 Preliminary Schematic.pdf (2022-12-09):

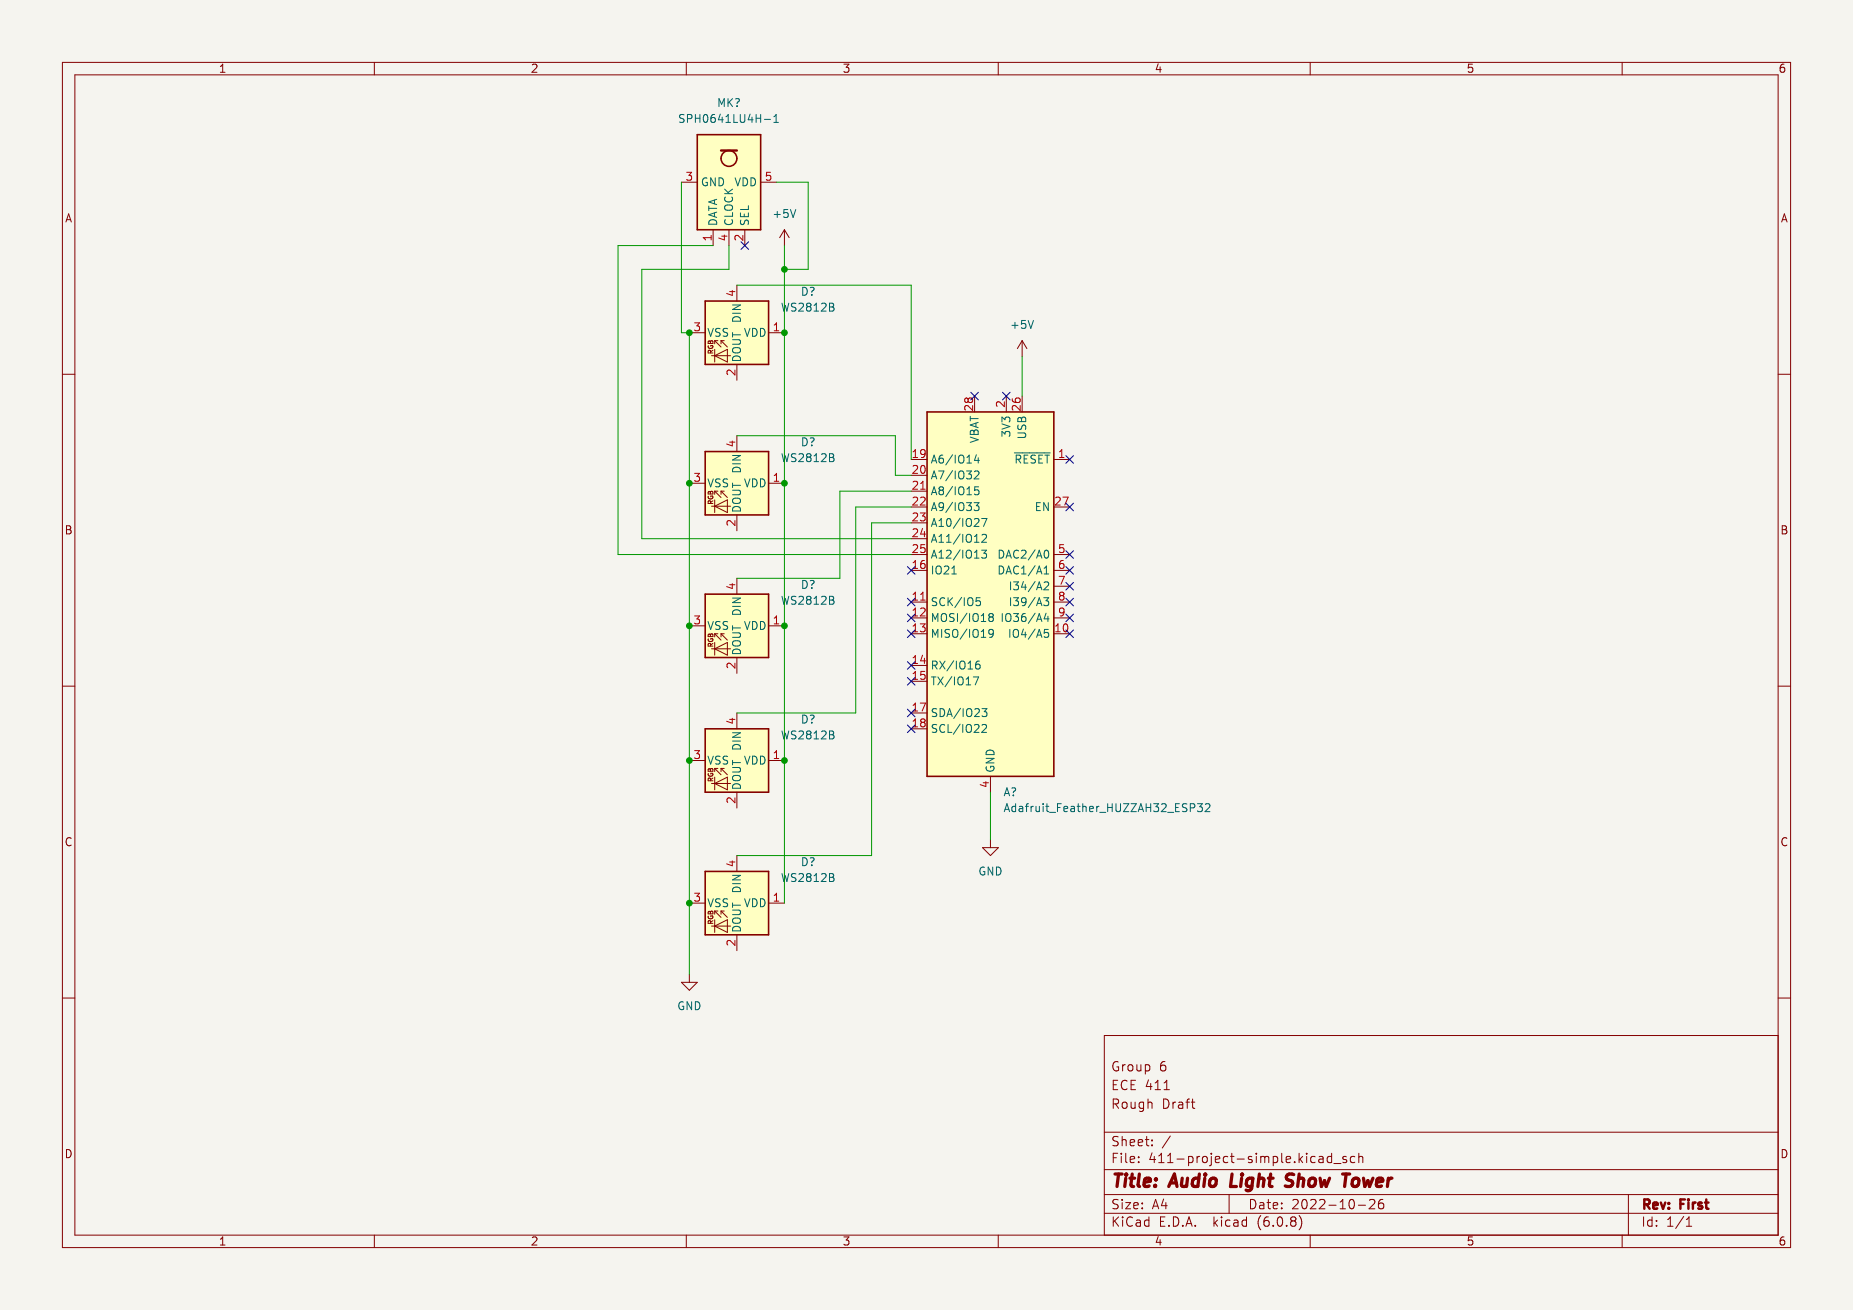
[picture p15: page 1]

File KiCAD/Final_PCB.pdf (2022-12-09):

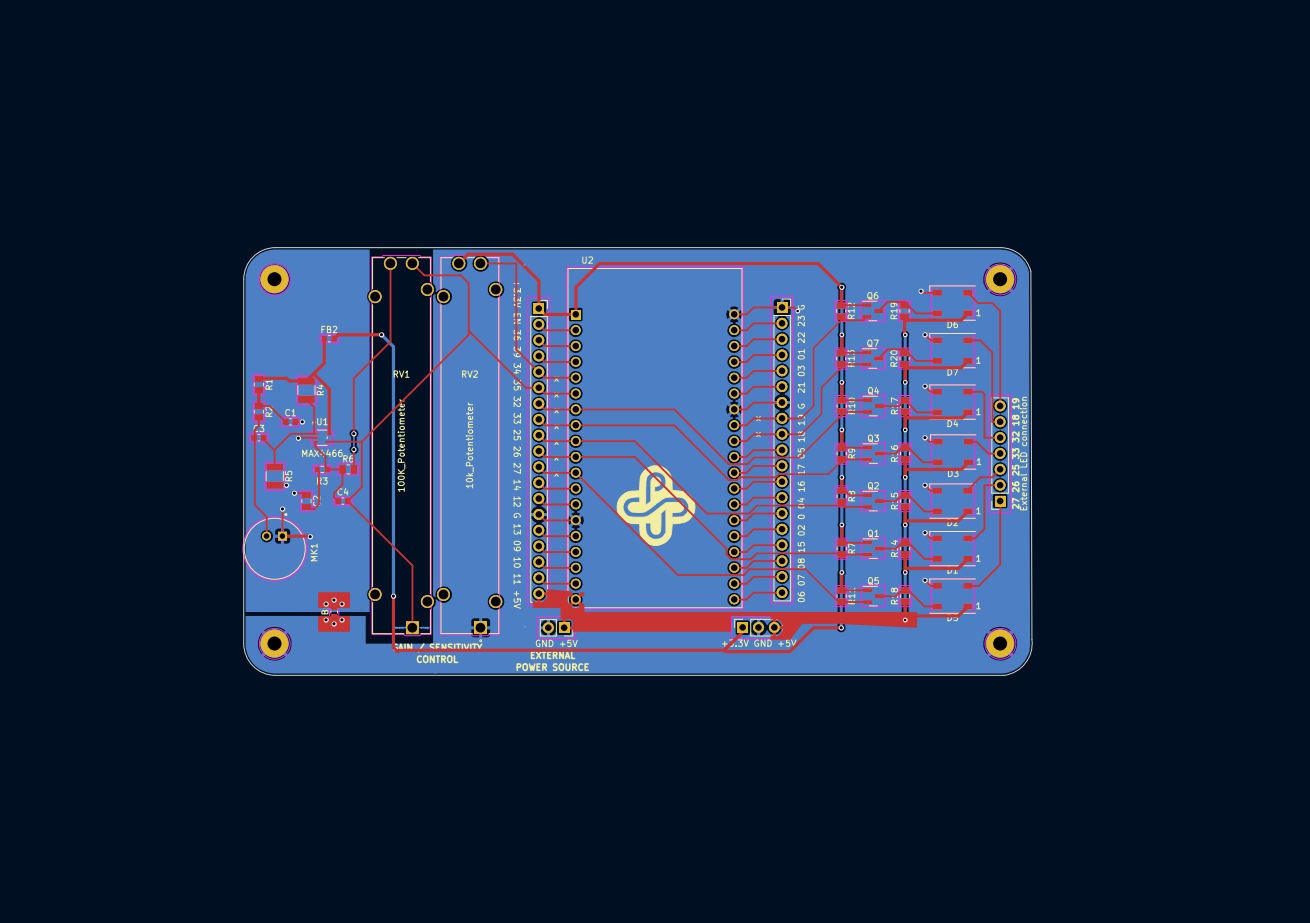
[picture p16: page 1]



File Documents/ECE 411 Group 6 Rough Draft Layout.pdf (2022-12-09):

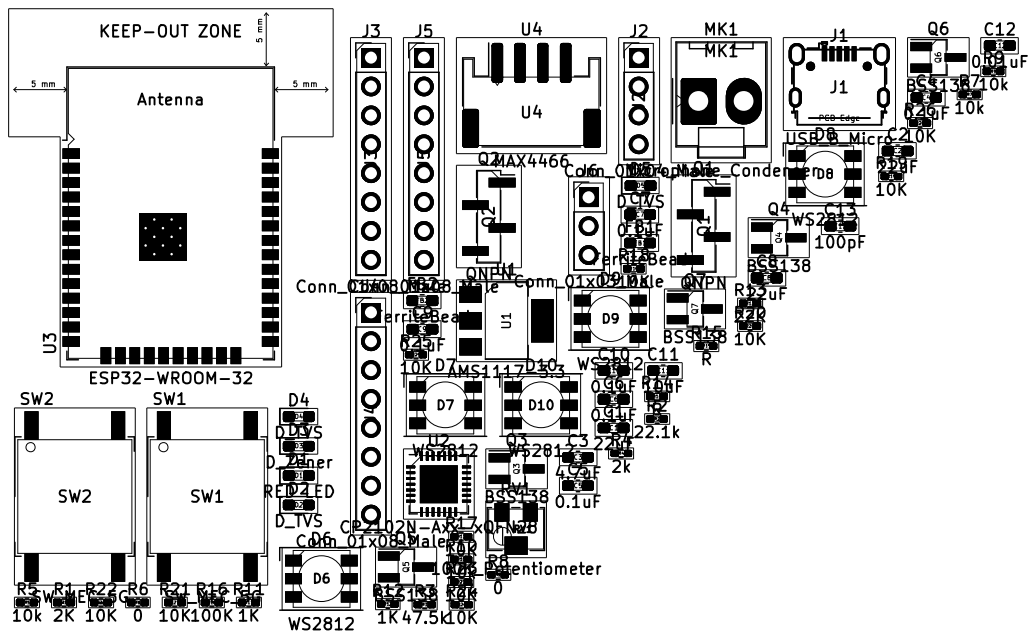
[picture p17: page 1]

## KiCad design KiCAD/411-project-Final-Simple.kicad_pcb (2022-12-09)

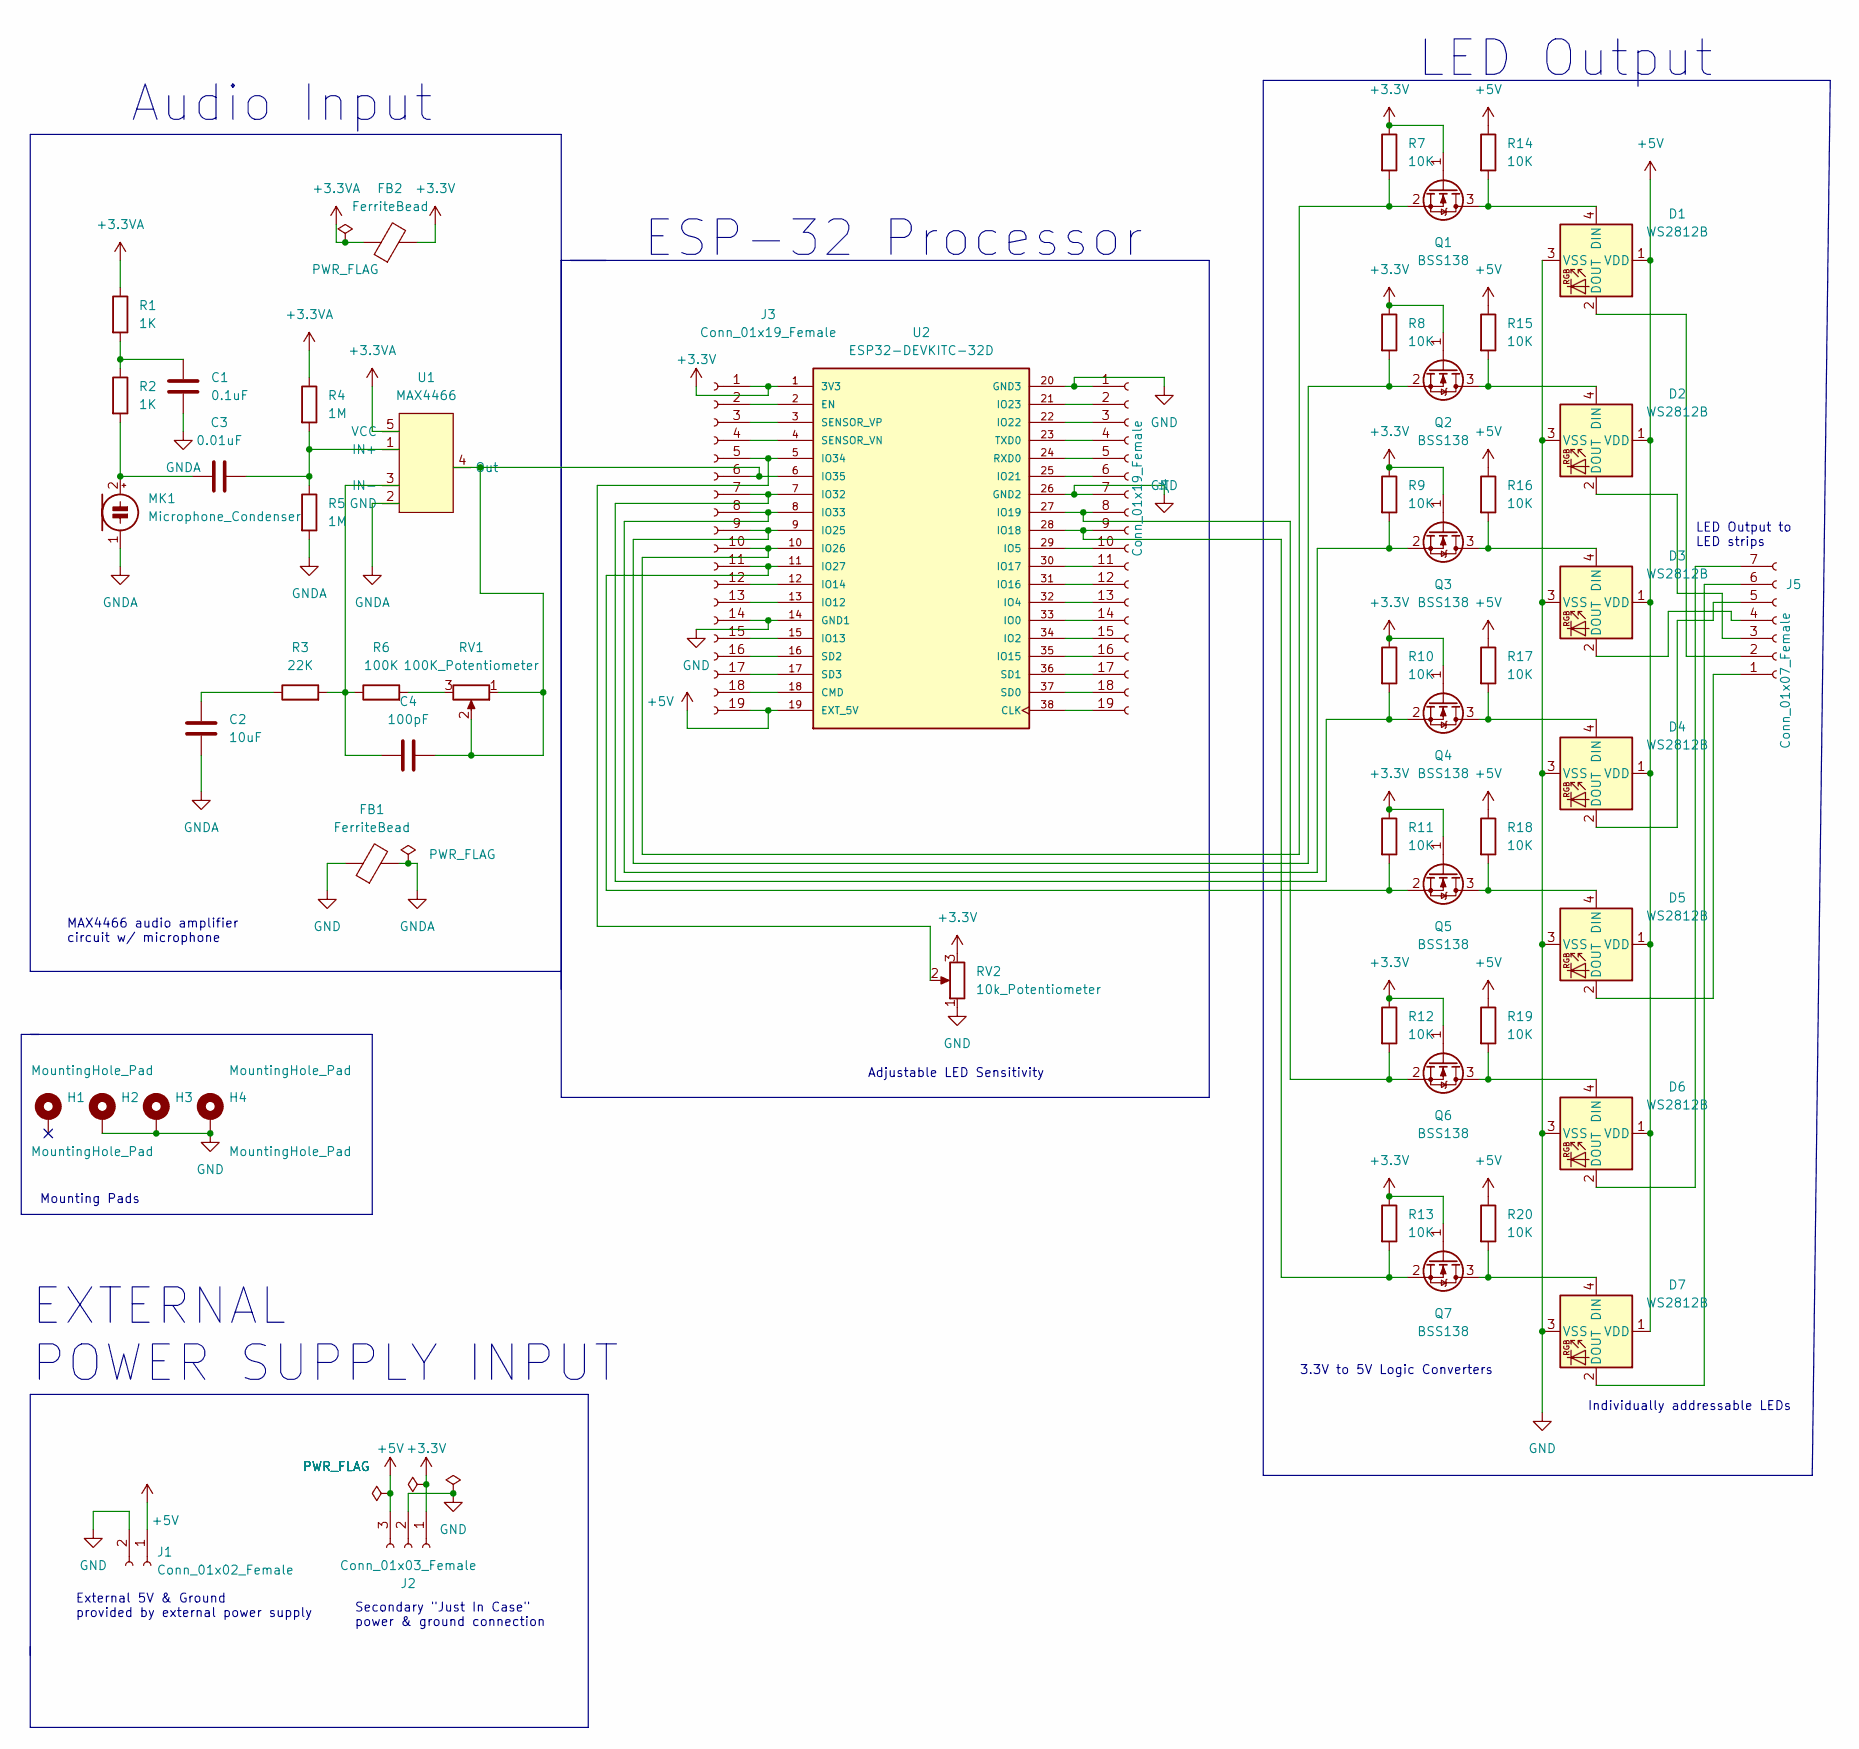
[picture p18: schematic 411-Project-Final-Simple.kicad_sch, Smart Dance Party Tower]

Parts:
C1: 0.1uF; C_0603_1608Metric
C2: 10uF; C_0805_2012Metric
C3: 0.01uF; C_0603_1608Metric
C4: 100pF; C_0603_1608Metric
D1, D2, D3, D4, D5, D6, D7: WS2812B; LED_WS2812B_PLCC4_5.0x5.0mm_P3.2mm
FB1, FB2: FerriteBead; L_0603_1608Metric
H1, H2, H3, H4: MountingHole_Pad; MountingHole_2.2mm_M2_Pad
J1: Conn_01x02_Female; PinSocket_1x02_P2.54mm_Vertical
J2: Conn_01x03_Female; PinSocket_1x03_P2.54mm_Vertical
J3, J4: Conn_01x19_Female; PinSocket_1x19_P2.54mm_Vertical
J5: Conn_01x07_Female; PinSocket_1x07_P2.54mm_Vertical
MK1: Microphone_Condenser; MIC_CMA-4544PF-W
Q1, Q2, Q3, Q4, Q5, Q6, Q7: BSS138; SOT-23
R1, R2: 1K; R_0805_2012Metric
R3: 22K; R_0603_1608Metric
R4, R5: 1M; R_1210_3225Metric
R6: 100K; R_0805_2012Metric
R7, R8, R9, R10, R11, R12, R13, R14, R15, R16, R17, R18, R19, R20: 10K; R_0805_2012Metric
RV1: 100K_Potentiometer; PTA4543-2015DPA103
RV2: 10k_Potentiometer; PTA4543-2015DPA103
U1: MAX4466; MAX4466EXK&plus_T
U2: ESP32-DEVKITC-32D; MODULE_ESP32-DEVKITC-32D; PARTREV 4

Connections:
+3.3V: FB2.2, J2.1, J3.1, Q1.1 (G), Q2.1 (G), Q3.1 (G), Q4.1 (G), Q5.1 (G), Q6.1 (G), Q7.1 (G), R7.1, R8.1, R9.1, R10.1, R11.1, R12.1, R13.1, RV2.3, U2.1 (3V3); also elsewhere on the board
+3.3VA: FB2.1, R1.1, R4.1, U1.5 (VCC)
+5V: D1.1 (VDD), D2.1 (VDD), D3.1 (VDD), D4.1 (VDD), D5.1 (VDD), D6.1 (VDD), D7.1 (VDD), J1.1, J2.3, J3.19, R14.1, R15.1, R16.1, R17.1, R18.1, R19.1, R20.1, U2.19 (EXT_5V); also elsewhere on the board
GND: D1.3 (VSS), D2.3 (VSS), D3.3 (VSS), D4.3 (VSS), D5.3 (VSS), D6.3 (VSS), D7.3 (VSS), FB1.1, H2.1, H3.1, H4.1, J1.2, J2.2, J3.14, J4.1, J4.7, RV2.1, U2.14 (GND1), U2.20 (GND3), U2.26 (GND2); also elsewhere on the board
GNDA: C1.2, C2.1, FB1.2, MK1.1 (-), R5.2, U1.2 (GND)
unnamed: C1.1, R1.2, R2.1
unnamed: C2.2, R3.1
unnamed: C3.1, MK1.2 (+), R2.2
unnamed: C3.2, R4.2, R5.1, U1.1 (IN+)
unnamed: C4.1, R3.2, R6.1, U1.3 (IN-)
unnamed 10: C4.2, J3.6, RV1.1, RV1.2, U1.4 (Out), U2.6 (IO35); also elsewhere on the board
unnamed 11: J3.2, U2.2 (EN); also elsewhere on the board
unnamed 12: J3.3, U2.3 (SENSOR_VP); also elsewhere on the board
unnamed 13: J3.4, U2.4 (SENSOR_VN); also elsewhere on the board
unnamed 14: J3.5, RV2.2, U2.5 (IO34); also elsewhere on the board
unnamed 15: J3.7, Q4.2 (S), R10.2, U2.7 (IO32); also elsewhere on the board
unnamed 16: J3.8, Q3.2 (S), R9.2, U2.8 (IO33); also elsewhere on the board
unnamed 17: J3.9, Q2.2 (S), R8.2, U2.9 (IO25); also elsewhere on the board
unnamed 18: J3.10, Q1.2 (S), R7.2, U2.10 (IO26); also elsewhere on the board
unnamed 19: J3.11, Q5.2 (S), R11.2, U2.11 (IO27); also elsewhere on the board
unnamed 20: J3.12, U2.12 (IO14); also elsewhere on the board
unnamed 21: J3.13, U2.13 (IO12); also elsewhere on the board
unnamed 22: J3.15, U2.15 (IO13); also elsewhere on the board
unnamed 23: J3.16, U2.16 (SD2); also elsewhere on the board
unnamed 24: J3.17, U2.17 (SD3); also elsewhere on the board
unnamed 25: J3.18, U2.18 (CMD); also elsewhere on the board
unnamed 26: J4.2, U2.21 (IO23); also elsewhere on the board
unnamed 27: J4.3, U2.22 (IO22); also elsewhere on the board
unnamed 28: J4.4, U2.23 (TXD0); also elsewhere on the board
unnamed 29: J4.5, U2.24 (RXD0); also elsewhere on the board
unnamed 30: J4.6, U2.25 (IO21); also elsewhere on the board
unnamed 31: J4.8, Q6.2 (S), R12.2, U2.27 (IO19); also elsewhere on the board
unnamed 32: J4.9, Q7.2 (S), R13.2, U2.28 (IO18); also elsewhere on the board
unnamed 33: J4.10, U2.29 (IO5); also elsewhere on the board
unnamed 34: J4.11, U2.30 (IO17); also elsewhere on the board
unnamed 35: J4.12, U2.31 (IO16); also elsewhere on the board
unnamed 36: J4.13, U2.32 (IO4); also elsewhere on the board
unnamed 37: J4.14, U2.33 (IO0); also elsewhere on the board
unnamed 38: J4.15, U2.34 (IO2); also elsewhere on the board
unnamed 39: J4.16, U2.35 (IO15); also elsewhere on the board
unnamed 40: J4.17, U2.36 (SD1); also elsewhere on the board
unnamed 41: J4.18, U2.37 (SD0); also elsewhere on the board
unnamed 42: J4.19, U2.38 (CLK); also elsewhere on the board
unnamed 43: D5.2 (DOUT), J5.1; also elsewhere on the board
unnamed 44: D1.2 (DOUT), J5.2; also elsewhere on the board
unnamed 45: D2.2 (DOUT), J5.3; also elsewhere on the board
unnamed 46: D3.2 (DOUT), J5.4; also elsewhere on the board
unnamed 47: D4.2 (DOUT), J5.5; also elsewhere on the board
unnamed 48: D7.2 (DOUT), J5.6; also elsewhere on the board
unnamed 49: D6.2 (DOUT), J5.7; also elsewhere on the board
unnamed: D1.4 (DIN), Q1.3 (D), R14.2
unnamed: D2.4 (DIN), Q2.3 (D), R15.2
unnamed: D3.4 (DIN), Q3.3 (D), R16.2
unnamed: D4.4 (DIN), Q4.3 (D), R17.2
unnamed: D5.4 (DIN), Q5.3 (D), R18.2
unnamed: D6.4 (DIN), Q6.3 (D), R19.2
unnamed: D7.4 (DIN), Q7.3 (D), R20.2
unnamed: R6.2, RV1.3

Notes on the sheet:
EXTERNAL POWER SUPPLY INPUT
MAX4466 audio amplifier circuit w/ microphone
External 5V & Ground provided by external power supply
LED Output
ESP-32 Processor
Individually addressable LEDs
Adjustable LED Sensitivity
Audio Input
3.3V to 5V Logic Converters
Mounting Pads
Secondary "Just In Case" power & ground connection
LED Output to LED strips

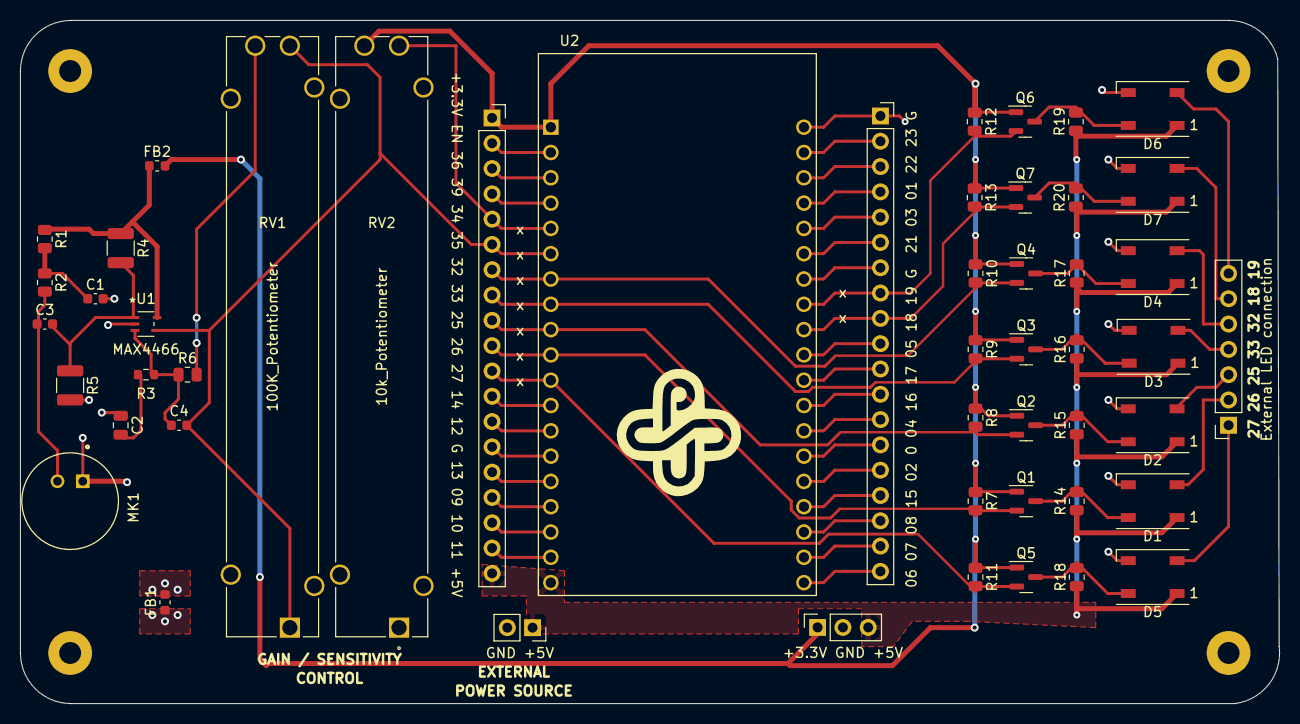
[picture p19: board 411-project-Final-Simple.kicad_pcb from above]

Board: 2 copper layers, 126.4 x 68.6 mm, 54 parts (0 on the bottom side), 58 nets.

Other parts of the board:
06 07 08 15 02 0 04 16 17 05 18 19 G  21 03 01 22 23 G: Conn_01x19_Female; PinSocket_1x19_P2.54mm_Vertical
+3.3V EN 36 39 34 35 32 33 25 26 27 14 12 G 13 09 10 11 +5V: Conn_01x19_Female; PinSocket_1x19_P2.54mm_Vertical
+3.3V GND +5V: Conn_01x03_Female; PinSocket_1x03_P2.54mm_Vertical
External LED connection: Conn_01x07_Female; PinSocket_1x07_P2.54mm_Vertical
GND +5V: Conn_01x02_Female; PinSocket_1x02_P2.54mm_Vertical

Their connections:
+3.3V: +3.3V EN 36 39 34 35 32 33 25 26 27 14 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.1, +3.3V GND +5V.1; also elsewhere on the board
+5V: +3.3V EN 36 39 34 35 32 33 25 26 27 14 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.19, +3.3V GND +5V.3, GND +5V.1; also elsewhere on the board
GND: 06 07 08 15 02 0 04 16 17 05 18 19 G 21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.1, 06 07 08 15 02 0 04 16 17 05 18 19 G 21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.7, +3.3V EN 36 39 34 35 32 33 25 26 27 14 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.14, +3.3V GND +5V.2, GND +5V.2; also elsewhere on the board
unnamed 10: +3.3V EN 36 39 34 35 32 33 25 26 27 14 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.6; also elsewhere on the board
unnamed 11: +3.3V EN 36 39 34 35 32 33 25 26 27 14 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.2; also elsewhere on the board
unnamed 12: +3.3V EN 36 39 34 35 32 33 25 26 27 14 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.3; also elsewhere on the board
unnamed 13: +3.3V EN 36 39 34 35 32 33 25 26 27 14 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.4; also elsewhere on the board
unnamed 14: +3.3V EN 36 39 34 35 32 33 25 26 27 14 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.5; also elsewhere on the board
unnamed 15: +3.3V EN 36 39 34 35 32 33 25 26 27 14 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.7; also elsewhere on the board
unnamed 16: +3.3V EN 36 39 34 35 32 33 25 26 27 14 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.8; also elsewhere on the board
unnamed 17: +3.3V EN 36 39 34 35 32 33 25 26 27 14 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.9; also elsewhere on the board
unnamed 18: +3.3V EN 36 39 34 35 32 33 25 26 27 14 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.10; also elsewhere on the board
unnamed 19: +3.3V EN 36 39 34 35 32 33 25 26 27 14 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.11; also elsewhere on the board
unnamed 20: +3.3V EN 36 39 34 35 32 33 25 26 27 14 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.12; also elsewhere on the board
unnamed 21: +3.3V EN 36 39 34 35 32 33 25 26 27 14 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.13; also elsewhere on the board
unnamed 22: +3.3V EN 36 39 34 35 32 33 25 26 27 14 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.15; also elsewhere on the board
unnamed 23: +3.3V EN 36 39 34 35 32 33 25 26 27 14 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.16; also elsewhere on the board
unnamed 24: +3.3V EN 36 39 34 35 32 33 25 26 27 14 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.17; also elsewhere on the board
unnamed 25: +3.3V EN 36 39 34 35 32 33 25 26 27 14 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.18; also elsewhere on the board
unnamed 26: 06 07 08 15 02 0 04 16 17 05 18 19 G 21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.2; also elsewhere on the board
unnamed 27: 06 07 08 15 02 0 04 16 17 05 18 19 G 21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.3; also elsewhere on the board
unnamed 28: 06 07 08 15 02 0 04 16 17 05 18 19 G 21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.4; also elsewhere on the board
unnamed 29: 06 07 08 15 02 0 04 16 17 05 18 19 G 21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.5; also elsewhere on the board
unnamed 30: 06 07 08 15 02 0 04 16 17 05 18 19 G 21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.6; also elsewhere on the board
unnamed 31: 06 07 08 15 02 0 04 16 17 05 18 19 G 21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.8; also elsewhere on the board
unnamed 32: 06 07 08 15 02 0 04 16 17 05 18 19 G 21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.9; also elsewhere on the board
unnamed 33: 06 07 08 15 02 0 04 16 17 05 18 19 G 21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.10; also elsewhere on the board
unnamed 34: 06 07 08 15 02 0 04 16 17 05 18 19 G 21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.11; also elsewhere on the board
unnamed 35: 06 07 08 15 02 0 04 16 17 05 18 19 G 21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.12; also elsewhere on the board
unnamed 36: 06 07 08 15 02 0 04 16 17 05 18 19 G 21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.13; also elsewhere on the board
unnamed 37: 06 07 08 15 02 0 04 16 17 05 18 19 G 21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.14; also elsewhere on the board
unnamed 38: 06 07 08 15 02 0 04 16 17 05 18 19 G 21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.15; also elsewhere on the board
unnamed 39: 06 07 08 15 02 0 04 16 17 05 18 19 G 21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.16; also elsewhere on the board
unnamed 40: 06 07 08 15 02 0 04 16 17 05 18 19 G 21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.17; also elsewhere on the board
unnamed 41: 06 07 08 15 02 0 04 16 17 05 18 19 G 21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.18; also elsewhere on the board
unnamed 42: 06 07 08 15 02 0 04 16 17 05 18 19 G 21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.19; also elsewhere on the board
unnamed 43: External LED connection.1; also elsewhere on the board
unnamed 44: External LED connection.2; also elsewhere on the board
unnamed 45: External LED connection.3; also elsewhere on the board
unnamed 46: External LED connection.4; also elsewhere on the board
unnamed 47: External LED connection.5; also elsewhere on the board
unnamed 48: External LED connection.6; also elsewhere on the board
unnamed 49: External LED connection.7; also elsewhere on the board

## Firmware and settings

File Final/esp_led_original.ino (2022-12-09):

#include <Adafruit_NeoPixel.h>
 
#define LED_Pin1 19 //use 33,32,27,26,25,19,18,14
#define LED_Pin2 18 //use 33,32,27,26,25,19,18,14
#define LED_Pin3 32 //use 33,32,27,26,25,19,18,14
#define LED_Pin4 33 //use 33,32,27,26,25,19,18,14
#define LED_Pin5 25 //use 33,32,27,26,25,19,18,14
#define LED_Pin6 26 //use 33,32,27,26,25,19,18,14
#define LED_Pin7 27 //use 33,32,27,26,25,19,18,14
#define Audio_Pin 36 // use 34 or 35
#define Pot_Pin 34 // use 34 or 35
#define LED_COUNT 76
//#define brightness 200
#define loopy 14
#define pause 40


Adafruit_NeoPixel pixels1 = Adafruit_NeoPixel(LED_COUNT, LED_Pin1, NEO_GRB + NEO_KHZ800);
Adafruit_NeoPixel pixels2 = Adafruit_NeoPixel(LED_COUNT, LED_Pin2, NEO_GRB + NEO_KHZ800);
Adafruit_NeoPixel pixels3 = Adafruit_NeoPixel(LED_COUNT, LED_Pin3, NEO_GRB + NEO_KHZ800);
Adafruit_NeoPixel pixels4 = Adafruit_NeoPixel(LED_COUNT, LED_Pin4, NEO_GRB + NEO_KHZ800);
Adafruit_NeoPixel pixels5 = Adafruit_NeoPixel(LED_COUNT, LED_Pin5, NEO_GRB + NEO_KHZ800);
Adafruit_NeoPixel pixels6 = Adafruit_NeoPixel(LED_COUNT, LED_Pin6, NEO_GRB + NEO_KHZ800);
Adafruit_NeoPixel pixels7 = Adafruit_NeoPixel(LED_COUNT, LED_Pin7, NEO_GRB + NEO_KHZ800);

const int num_pixels = pixels7.numPixels();
 int a=0;
 int b=10;
 int c=20;
 int d=30;
 int e=40;
 int f=50;


#define Pot_Pin 34 // use 34 or 35



const int sampleWindow = 50; // Sample window width in mS (50 mS = 20Hz)

int volume = 0;

int loopLED = 0;
int direct = 0;
int brightness = 255;

int colors = 0;
//uint32_t violet = [148,0,211];






void colorSweep(uint32_t color, int wait) {
  for(int i=0; i<pixels7.numPixels(); i++) { // For each pixel in strip...
   // pixels.setPixelColor(i, color);         //  Set pixel's color (in RAM)

  // pixels1.setPixelColor(i, random(brightness),random(brightness),random(brightness));
  // pixels2.setPixelColor(i, random(brightness),random(brightness),random(brightness));
  // pixels3.setPixelColor(i, random(brightness),random(brightness),random(brightness));
  // pixels4.setPixelColor(i, random(brightness),random(brightness),random(brightness));
  // pixels5.setPixelColor(i, random(brightness),random(brightness),random(brightness));
  // pixels6.setPixelColor(i, random(brightness),random(brightness),random(brightness));
   pixels7.setPixelColor(i, random(brightness),random(brightness),random(brightness));
   if (i ==0){}
   else{
  // pixels1.setPixelColor(i-1,0,0,0);
  // pixels2.setPixelColor(i-1,0,0,0);
  // pixels3.setPixelColor(i-1,0,0,0);
  // pixels4.setPixelColor(i-1,0,0,0);
  // pixels5.setPixelColor(i-1,0,0,0);
  // pixels6.setPixelColor(i-1,0,0,0);
   pixels7.setPixelColor(i-1,0,0,0);}
   //pixels1.show();                         //  Update strip to match
   //pixels2.show();
   //pixels3.show();
   //pixels4.show();
   //pixels5.show();
   //pixels6.show();
   pixels7.show();
    delay(wait);                           //  Pause for a moment
  } 
  //pixels1.setPixelColor(num_pixels-1,0,0,0);
  //pixels1.show();
  //pixels2.setPixelColor(num_pixels-1,0,0,0);
 // pixels2.show();
  //pixels3.setPixelColor(num_pixels-1,0,0,0);
  //pixels3.show();
  //pixels4.setPixelColor(num_pixels-1,0,0,0);
  //pixels4.show();
  //pixels5.setPixelColor(num_pixels-1,0,0,0);
  //pixels5.show();
 // pixels6.setPixelColor(num_pixels-1,0,0,0);
  //pixels6.show();
  pixels7.setPixelColor(num_pixels-1,0,0,0);
  pixels7.show();
  
                  
}



void colorSweep2(uint32_t color, int wait, int i) {
   // For each pixel in strip...
   // pixels.setPixelColor(i, color);         //  Set pixel's color (in RAM)

//   pixels1.setPixelColor(i, random(brightness),random(brightness),random(brightness));
//   pixels2.setPixelColor(i, random(brightness),random(brightness),random(brightness));
//   pixels3.setPixelColor(i, random(brightness),random(brightness),random(brightness));
//   pixels4.setPixelColor(i, random(brightness),random(brightness),random(brightness));
//   pixels5.setPixelColor(i, random(brightness),random(brightness),random(brightness));
//   pixels6.setPixelColor(i, random(brightness),random(brightness),random(brightness));
   pixels7.setPixelColor(i, random(brightness),random(brightness),random(brightness));
   if (i ==0){}
   else{
//   pixels1.setPixelColor(i-1,0,0,0);
//   pixels2.setPixelColor(i-1,0,0,0);
//   pixels3.setPixelColor(i-1,0,0,0);
//   pixels4.setPixelColor(i-1,0,0,0);
//   pixels5.setPixelColor(i-1,0,0,0);
//   pixels6.setPixelColor(i-1,0,0,0);
   pixels7.setPixelColor(i-1,0,0,0);}
   //pixels1.show();                         //  Update strip to match
   //pixels2.show();
   //pixels3.show();
   //pixels4.show();
   //pixels5.show();
   //pixels6.show();
   pixels7.show();
    //delay(wait);                           //  Pause for a moment
  
  
                 
}

int colorme = 0;
int loopady = 0;

void colorSweep3(uint32_t color, int wait) {

colorme = colors;
  
  for(int i=0; i<pixels7.numPixels()-loopy; i++) { // For each pixel in strip...
   // pixels.setPixelColor(i, color);         //  Set pixel's color (in RAM)
   
  
   if (i<volume){
  
   //pixels7.setPixelColor(i, random(brightness),random(brightness),random(brightness));}
   if (colorme == 0){

   pixels7.setPixelColor(i, 148,0,211);} //violet
   if (colorme == 1){

   pixels7.setPixelColor(i, 75,0,130);} //Purple
   if (colorme == 2){

   pixels7.setPixelColor(i, 0,0,255);} //Blue
   if (colorme == 3){

   pixels7.setPixelColor(i, 0,255,0);} //Green
   if (colorme == 4){

   pixels7.setPixelColor(i, 255,255,0);} //Yellow
   if (colorme == 5){

   pixels7.setPixelColor(i, 255,127,0);} //Orange
   if (colorme == 6){
    colorme = -1;
   pixels7.setPixelColor(i, 255,0,0);}} //Red

   else{
   pixels7.setPixelColor(i,0,0,0);}


 colorme++;
                          //  Pause for a moment
  } 

//
// if (direct==0){
//   pixels7.setPixelColor(pixels7.numPixels()+ loopLED++, random(brightness),random(brightness),random(brightness));
// }
// else{
// pixels7.setPixelColor(pixels7.numPixels()+ loopLED--, random(brightness),random(brightness),random(brightness));
// }
//if (loopLED>loopy){
//  direct=1;
//}
//if (loopLED<0){
//  direct=0;
//}

 for (int i=0; i<loopy;i++){
   pixels7.setPixelColor(pixels7.numPixels()-i, 0,0,0);
  
 }


if (direct ==0){
if (loopady<loopy){
pixels7.setPixelColor(pixels7.numPixels()-loopady, 148,0,255);}
loopady++;
if (loopady == loopy){
  direct = 1;
}
}


if (direct ==1){
if (loopady<loopy){
pixels7.setPixelColor(pixels7.numPixels()+loopady, random(brightness),random(brightness),random(brightness));}
loopady--;
if (loopady == 0){
  direct = 0;
}
}



// for (int i=0; i<loopy;i++){
//   pixels7.setPixelColor(pixels7.numPixels()-i, random(brightness),random(brightness),random(brightness));
//  
// }

   pixels7.show();
   delay(wait); 
 colors++;
 if (colors==7){
  colors = 0;
 }
                  
}


/////////////////////////////////////////////////////////////////////////////////////////////
int common = 0;
int sample = 0;
int audio = 0;



void codeForTask1( void * parameter ) {
   for (;;) {

   unsigned long startMillis= millis();  // Start of sample window
   unsigned int peakToPeak = 0;   // peak-to-peak level

   unsigned int signalMax = 0;
   unsigned int signalMin = 4095;

   // collect data for 50 mS
   while (millis() - startMillis < sampleWindow)
   {
      sample = analogRead(Audio_Pin);
      //Serial.println(sample);
      if (sample < 4095)  // toss out spurious readings
      {
         if (sample > signalMax)
         {
            signalMax = sample;  // save just the max levels
            //Serial.println(signalMax);
         }
         else if (sample < signalMin)
         {
            signalMin = sample;  // save just the min levels
            //Serial.println(signalMin);
         } }}
   peakToPeak = signalMax - signalMin;  // max - min = peak-peak amplitude
   Serial.println("PeaktoPeak");
   Serial.println(peakToPeak);
   double volts = (peakToPeak * 3.3) / 4095;  // convert to volts
   double volumeDouble = (peakToPeak * LED_COUNT) / 4095;  // convert to volts
   volume = round(volumeDouble);
   Serial.println(volts);
   if(volts>2){
   
      if (a>=10){a=0;}
      if (b>=20){b=10;}
      if (c>=30){c=20;}
      if (d>=40){d=30;}
      if (e>=50){e=40;}
      if (f>=60){f=50;}
 
   }
sample = analogRead(Pot_Pin);
Serial.println(sample);

sample = 4095;

double brightnessDouble = 255 * sample / 4095;
brightness = round(brightnessDouble);

   }}




void codeForTask2( void * parameter ) {
   for (;;) {
      Serial.print("                     Code is running on Core: ");Serial.println( xPortGetCoreID());
      //sum_numbers();
      Serial.print("Global var");
      Serial.print(common);
      common=common+1;
      for(int i=0; i<pixels7.numPixels(); i++) {
      colorSweep3(pixels7.Color(random(brightness),   random(brightness),   random(brightness)), pause); 
      //colorSweep2(pixels7.Color(random(brightness),   random(brightness),   random(brightness)), pause,b++); 
      //colorSweep2(pixels7.Color(random(brightness),   random(brightness),   random(brightness)), pause,c++); 
      //colorSweep2(pixels7.Color(random(brightness),   random(brightness),   random(brightness)),pause,d++); 
      //colorSweep2(pixels7.Color(random(brightness),   random(brightness),   random(brightness)), pause,e++); 
      //colorSweep2(pixels7.Color(random(brightness),   random(brightness),   random(brightness)), pause,f++); 
//      if (a==pixels1.numPixels()){a=0;}
//      if (b==pixels1.numPixels()){b=0;}
//      if (c==pixels1.numPixels()){c=0;}
//      if (d==pixels1.numPixels()){d=0;}
//      if (e==pixels1.numPixels()){e=0;}
//      if (f==pixels1.numPixels()){f=0;}}
      }

            sample = analogRead(Pot_Pin);
      Serial.println(sample);
      //delay(1000);

   }
}




TaskHandle_t Task1, Task2;




void setup() {
   Serial.begin(115200);


   //pixels1.begin(); // This initializes the NeoPixel library.
   //pixels2.begin();
   //pixels3.begin();
   //pixels4.begin();
   //pixels5.begin();
   //pixels6.begin();
   pixels7.begin();
randomSeed(analogRead(0));


   
   /*Syntax for assigning task to a core:
   xTaskCreatePinnedToCore(
                    coreTask,   // Function to implement the task
                    "coreTask", // Name of the task 
                    10000,      // Stack size in words 
                    NULL,       // Task input parameter 
                    0,          // Priority of the task 
                    NULL,       // Task handle. 
                    taskCore);  // Core where the task should run 
   */
   xTaskCreatePinnedToCore(    codeForTask1,    "FibonacciTask",    5000,      NULL,    2,    &Task1,    0);
   //delay(500);  // needed to start-up task1
   xTaskCreatePinnedToCore(    codeForTask2,    "SumTask",    5000,    NULL,    2,    &Task2,    1);
}





void loop() {
  
  
  }

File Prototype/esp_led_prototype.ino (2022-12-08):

#include <Adafruit_NeoPixel.h>
 
#define LED_Pin 19 //use 33,32,27,26,25,19,18,14
#define Audio_Pin 35 // use 34 or 35
#define Pot_Pin 34 // use 34 or 35
#define LED_COUNT 50
Adafruit_NeoPixel pixels = Adafruit_NeoPixel(LED_COUNT, LED_Pin, NEO_GRB + NEO_KHZ800);
 
const int sampleWindow = 50; // Sample window width in mS (50 mS = 20Hz)
unsigned int sample;
const int num_pixels = pixels.numPixels();
void setup() 
{
   Serial.begin(115200);
   pixels.begin(); // This initializes the NeoPixel library.
randomSeed(analogRead(0));
}


void loop() 
{
   unsigned long startMillis= millis();  // Start of sample window
   unsigned int peakToPeak = 0;   // peak-to-peak level

   unsigned int signalMax = 0;
   unsigned int signalMin = 4095;

   // collect data for 50 mS
   while (millis() - startMillis < sampleWindow)
   {
      sample = analogRead(Audio_Pin);
      if (sample < 4095)  // toss out spurious readings
      {
         if (sample > signalMax)
         {
            signalMax = sample;  // save just the max levels
         }
         else if (sample < signalMin)
         {
            signalMin = sample;  // save just the min levels
         }
      }
   }
   peakToPeak = signalMax - signalMin;  // max - min = peak-peak amplitude
   double volts = (peakToPeak * 3.3) / 4095;  // convert to volts

   Serial.println(volts);
   if(volts>2){
   colorSweep(pixels.Color(random(255),   random(255),   random(255)), 10);}
   
}




void colorSweep(uint32_t color, int wait) {
  for(int i=0; i<pixels.numPixels(); i++) { // For each pixel in strip...
   // pixels.setPixelColor(i, color);         //  Set pixel's color (in RAM)

   pixels.setPixelColor(i, random(255),random(255),random(255));
   if (i ==0){}
   else{
   pixels.setPixelColor(i-1,0,0,0);}
    pixels.show();                          //  Update strip to match
    delay(wait);                           //  Pause for a moment
  } 
  pixels.setPixelColor(num_pixels-1,0,0,0);
    pixels.show();
                  
}

























//  
//uint32_t chipId = 0;
//int x =0;
//void setup() {
//  Serial.begin(115200);
//}
//
//void loop() {
//  for(int i=0; i<17; i=i+8) {
//    chipId |= ((ESP.getEfuseMac() >> (40 - i)) & 0xff) << i;
//  }
//
//  Serial.printf("ESP32 Chip model = %s Rev %d\n", ESP.getChipModel(), ESP.getChipRevision());
//  Serial.printf("This chip has %d cores\n", ESP.getChipCores());
//  Serial.print("Chip ID: "); Serial.println(chipId);
//    Serial.print(x);
//  x++;
//  delay(3000);
//
//}

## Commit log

2022-11-06 Breadboard Prototype
2022-12-08 Finished LED tower
2022-12-08 Prototype code
    This code communicated only for a single LED strip and single core for the ESP-32.
2022-12-08 KiCAD files
2022-12-09 Bill of Materials
    [ECE 411 Group 6 Bill of Materials.xlsx]
2022-12-09 Preliminary Schematic
2022-12-09 Updated Schematic Prelim Layout
2022-12-09 Rough Draft Layout/ Schematic
2022-12-09 Final CAD Design

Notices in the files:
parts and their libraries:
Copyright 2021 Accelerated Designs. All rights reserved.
